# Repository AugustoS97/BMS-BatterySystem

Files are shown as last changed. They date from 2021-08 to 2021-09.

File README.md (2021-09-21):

# BMS-BatterySystem
Repositorio con el diseño de un BMS y una batería como Trabajo de Fin de Máster.
- Autor: Augusto Samuel Hernández Martín
- Tutor: Fernando Luis Rosa González
- Co-Tutor: Iván Rodríguez Méndez
- Titulación: Máster en Ingeniería Industrial
- Universidad de La Laguna, 2021

# Licencia
- El paquete: [GPLv3](LICENSE) © 2021 Augusto Samuel Hernández Martín - Universidad de La Laguna

# Resumen 
El presente Trabajo Fin de Máster consiste en el diseñado y fabricación de un Sistema de Gestión de Batería (BMS), así como una batería modular configurable a diferentes tensiones y capacidades, con el objetivo de poder alimentar sistemas electrónicos aislados como los dispositivos de capturas de índices de significación eco-acústicos. Se ha llevado a cabo el diseño electrónico de los diferentes módulos que forman el sistema de alimentación y gestión así como el cálculo y diseño de la batería a partir de celdas de ion-litio y su estructura mecánica. Para poder alimentar dicho sistema se ha dimensionado una posible instalación generadora, empleando energía fotovoltaica. Finalmente, se ha realizado la fabricación de los distintos elementos, tanto mecánicos como electrónicos, y el desarrollo software de las diferentes herramientas necesarias para la configuración del BMS, la captura y el análisis de los datos generados. Por último, se han propuesto y analizado diferentes aplicaciones, además de la mencionada como objetivo principal del proyecto, para este sistema de BMS y acumulador.

# Abstract

In the present Master’s Degree Final Project, a Battery Management System (BMS) has been designed and manufactured, as well as a modular battery configurable at different voltages and capacities, with the aim of being able to power isolated electronic systems such as devices for capturing eco-acoustic significance indexes. The electronic design of the different modules that make up the power supply and management system has been carried out, as well as the calculation and design of the battery based on lithium-ion cells and its mechanical structure. In order to be able to supply this system, a possible generating installation has been dimensioned, using photovoltaic energy. Finally, the manufacture of the different elements, both mechanical and electronic, and the software development of the different tools necessary for the configuration of the BMS and the capture and analysis of the data generated have been carried out. Finally, different applications have been proposed and analysed, in addition to the one mentioned as the main objective of the project, for this BMS and accumulator system.

# Imágenes del sistema desarrollado
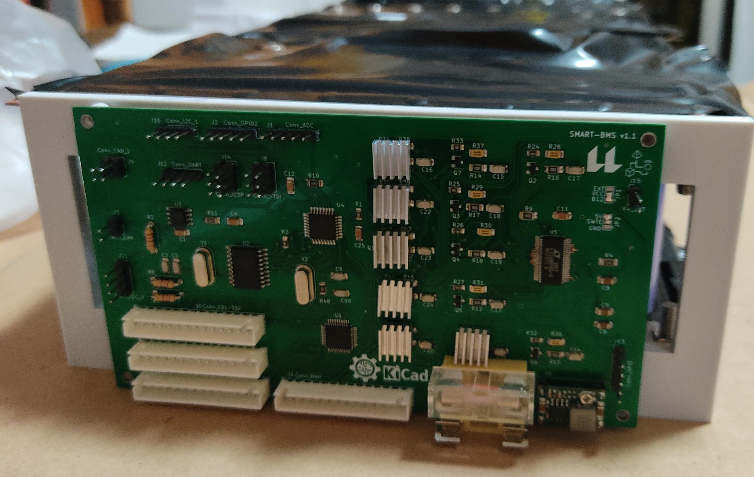
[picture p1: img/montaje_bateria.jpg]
BMS


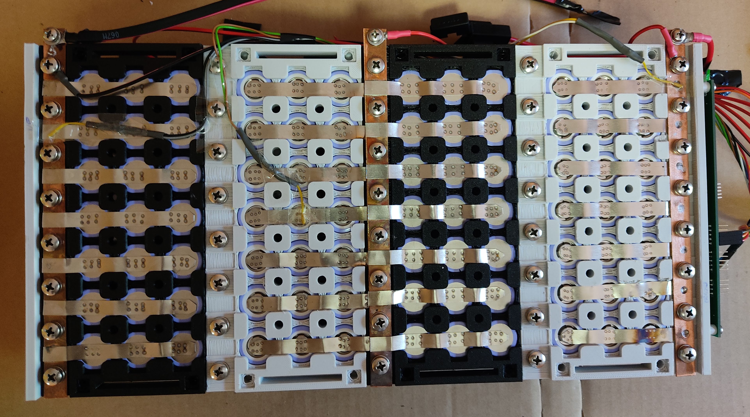
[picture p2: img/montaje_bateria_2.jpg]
Bateria


# Sistema diseñado

El diagrama de bloques del sistema de alimentación y la batería es el siguiente:

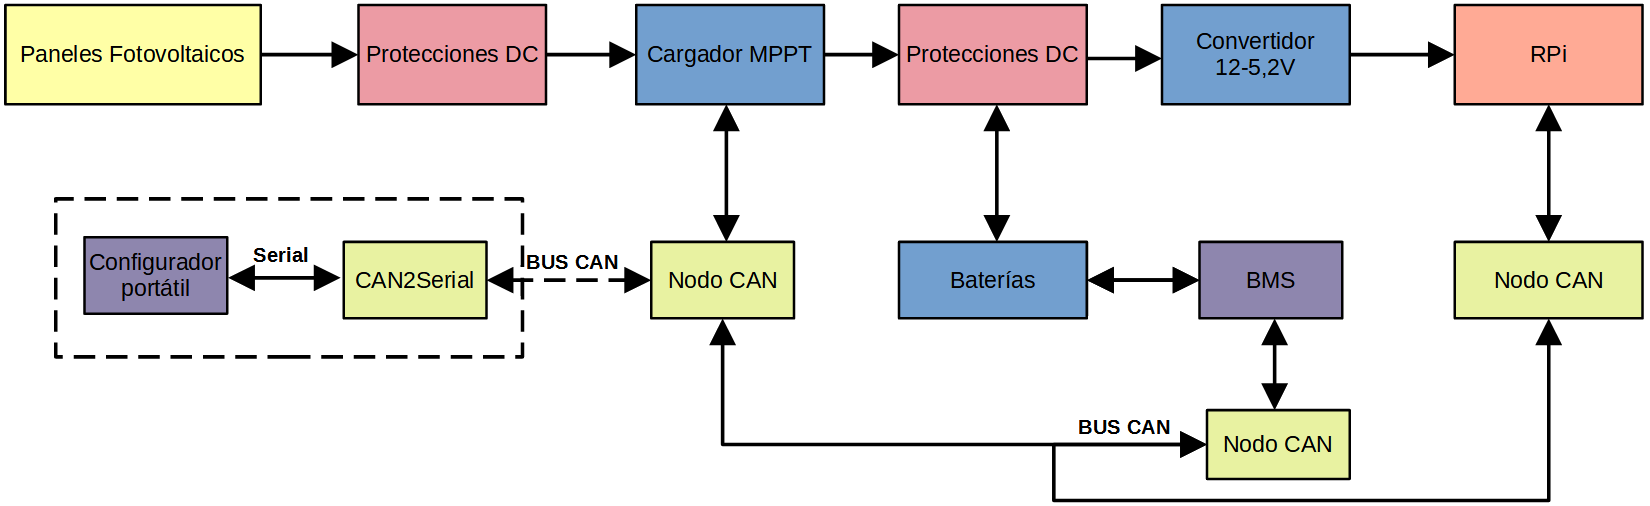
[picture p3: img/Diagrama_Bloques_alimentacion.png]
Diagrama de bloques del Sistema


La batería diseñada es la siguiente:
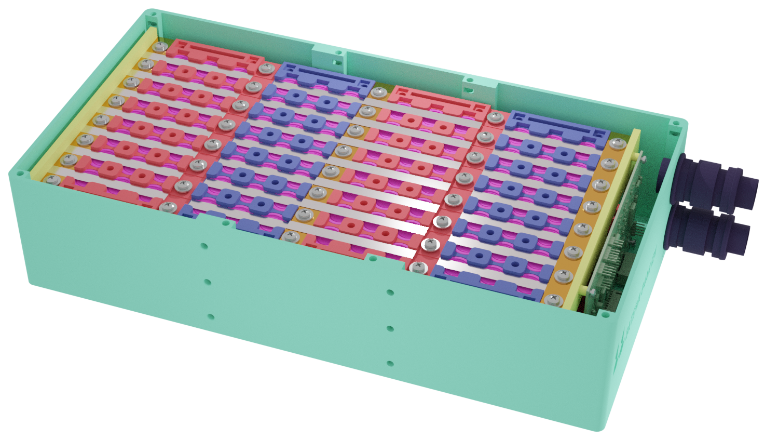
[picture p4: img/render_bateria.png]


Los módulos electrónicos diseñados son los siguientes:

## BMS
Diagrama de bloques del Sistema

## CAN2Serial
Diagrama de bloques del Sistema

## CAN2RS485
Diagrama de bloques del Sistema

# Contenido del repositorio

## Software
- BMS CAN Programmer: Puede encontrarse la herramienta BMS_CAN_Programer_GUI que debe ejecutarse en Linux con Qt 5 instalado. Y el firmware preparado para grabar en un ATMega 328P empleando la herramienta PlatformIo que realiza la conversión de los mensajes CAN del BMS desarrollado a mensajes serial que son leídos por la herramienta BMS_CAN_Programmer_GUI.
- SOC_estimation: Contiene los ficheros .csv de diferentes ensayos realizados a las celdas INR21700 de Samsung y en el directorio /src el script a ejecutar por terminal para obtener las curvas del ensayo. La carpeta /figures contiene las gráficas generadas.
- SmartBMS: Contiene el firmware del microcontrolador ATMega 328P del módulo de BMS. Debe flashearse empleando Platformio.
- bms_data_processing: Herramienta para ejecutar desde terminal e indicar la ruta del fichero .csv de datos del BMS generado así como número de celdas en serie y número de termistores.
-  power-monitor: Herramienta para instalar en una Raspberry Pi 3B+ que monitoriza el consumo de la misma a partir de las lecturas del integrado INA219 vía I2C. Almacena los ficheros capturados en un .json dentro del directorio /usr/share/power/data. Se generta un serivicio del sistema que puede ser gestionado mediante systemd.
-  power-data-processing: Herramienta que genera los gráficos de los datos capturados por power-monitor. Accede directamente a la ruta /home/$USER/power-data/data. Los diferentes ficheros python deben ubicarse en /home/$USER/power-data/src.

## Diseno-Electronico
- SmartBMS: Módulo electrónico de un BMS pra la medición de hasta 12 paquetes de celdas en serie, con comunicación CAN y medición de hasta 32 termistores NTC de 10KOhm. Opera con tensiones de alimentación de hasta 75V.
- CAN2Serial: Módulo electrónico para la interfaz de conversión de CAN a Serial para emplear la herramienta BMS_Programer_GUI y configurar el BMS.
- EPSolar-CAN: Módulo electrónico para la conversión de los mensajes CAN del BMS a mensajes para un cargador solar EPEver (mediante RS485).

## Diseno-Mecanico
- Bateria_horizontal.FCStd: Fichero FreeCAD con el diseño de un sistema de batería modular de 14.4V y 84Ah.
- Carcasa_Can2Serial.FCStd: Fichero FreeCAD con el diseno e la carcasa para la placa de circuito impreso de CAN2Serial
- STL: Contiene los modelos 3D de las diferentes piezas.

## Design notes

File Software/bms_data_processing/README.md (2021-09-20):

# BMS-data-processing
Script de python 3 para ejecutar desde terminal. Permite generar las gráficas de estado de la batería y el BMS a partir de los datos recogidos por el BMS a través de la herramienta BMS-Programmer-GUI. El código fuente se localiza en '/src', las figuras generadas en 'figures' y los datos en 'data'

# Licencia
- El paquete: [GPLv3](LICENSE) © 2021 Augusto Samuel Hernández Martín - Universidad de La Laguna

# Requerimientos Python
Se precisan las siguientes librerías:
~~~
- os
- datetime
- time
- json
- pathlib
- subprocess
- requests
- sys
- numpy
- csv
~~~

# Ejecucion del script

Se debe ejecutar desde terminal como se indica:
~~~
python3 bms-data-processing-d nombre_fichero.csv number_of_cells number_of_temp_sensor
~~~

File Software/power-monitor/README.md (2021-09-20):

# power-data

## Descripción
Software desarrollado para monitorizar el consumo de corriente y la tensión de un
sistema usando el integrado INA-219 (https://pypi.org/project/pi-ina219/) y la conexión I2C a una Raspberry PI.
El servicio del sistema se ejecuta cada 5 minutos y almacena en un fichero .json los
datos capturados del día correspondiente, ordenados en directorios.

# Licencia
- El paquete: [GPLv3](LICENSE) © 2021 Augusto Samuel Hernández Martín - Universidad de La Laguna

## Requerimientos
Requiere el módulo de Python INA219.

    $ sudo apt-get install python3-pip
    $ sudo pip3 install pi-ina219

Para la compilación del paquete .deb requiere:
~~~
  - dh-make
  - debmake
  - debhelper
  - devscripts
  - dpkg-dev
  - make
  - python3
  - build-essential
~~~

## Empaquetado

Para hacer el paquete con el servicio del sistema, se debe ejecutar:

    $ debuild -us -uc

Se debe estar en la carpeta 'power_monitor_d.

Mas información [aquí](https://blog.packagecloud.io/eng/2016/12/15/howto-build-debian-package-containing-simple-shell-scripts/ "Documentación dh-make").

## Localización de la instalación

Una vez instalado el .deb se genera un directorio en /usr/share llamado 'power-data'
que contiene 'src', 'data' y 'logs', donde se aloja el script, los datos y los logs.
Los ficheros del servicio de superusuario se alojan en '/lib/systemd/system'

    $ sudo dpkg -i power-monitor-d_1.0_all.deb

## Desinstalación

Para proceder a desinstalar el paquete, debe ejecutarse:

    $ sudo dpkg -r power-monitor-d

Se eliminan todos los ficheros salvo la ruta '/usr/share/power-data/data' que debe eliminarse a mano (para permitir no perder los datos .json).

## Revisión del estado del timer y el servicio

    $ systemctl status power-monitor-d.service
    $ systemctl status power-monitor-d.timer
    $ systemctl start power-monitor-d.service
    $ systemctl stop power-power_monitor_d.service
    $ systemctl daemon-reload

## Licencia
- El paquete: [GPLv3](LICENSE) © 2021 Augusto Samuel Hernández Martín - Universidad de La Laguna

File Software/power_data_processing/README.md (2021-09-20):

# BMS-data-processing
Script de python 3 para ejecutar desde terminal. Permite generar las gráficas de los datos recogidos por el servicio del sistema 'power-monitor'. La carpeta 'power-data' debe localizar en '/home/$USER/power-data'. El código fuente se localiza en '/src', los logs de procesamiento en '/logs' y los datos en '/data'.

# Licencia
- El paquete: [GPLv3](LICENSE) © 2021 Augusto Samuel Hernández Martín - Universidad de La Laguna

# Estructra de ficheros
El conjunto de ficheros deben de localizarse de la siguiente forma:

~~~
|--- power-data
|--- data
|   |--- Year
|   |   |--- Month
|   |   |   |--- Day
|   |   |   |   |--- power-dataYYMMDDDD.json
|--- src
|   |--- power_data_plot_tools
|   |--- power_data_tools
|   |-- power-data-processing-d
|--- logs
|   |--- _processed_plot.log
|   |--- power-data.log
~~~

# Requerimientos Python
Se precisan las siguientes librerías:
~~~
- matplotlib
- os
- datetime
- time
- json
- pathlib
- subprocess
- requests
- sys
- numpy
- csv
~~~

# Ejecucion del script

Se debe ejecutar desde terminal como se indica:
~~~
python3 power-data-processing-d
~~~

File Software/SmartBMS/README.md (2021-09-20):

# BMS
Firmware del nodo BMS que monitoriza la tensión, la temperatura de las celdas, la corriente
y realiza el balanceo de las celdas, cuando la diferencia entre celdas supera un valor establecido.
Transmite los parámetros medidos por CANBUS y puede ser configurado mediante CANBUS.

# Licencia
- El paquete: [GPLv3](LICENSE) © 2021 Augusto Samuel Hernández Martín - Universidad de La Laguna

# Mensajes CAN
A continuación se indican los mensajes CAN que son intercambiados entre el nodo BMS y el resto de nodos.

### Warning. Mensaje CAN
- Este mensaje es envíado por el BMS cuando hay una sobretemperatura o una tensión demasiado baja o alta. Su ID = 0x00 y está formado por 1 byte. Los bits a 1 indican las alertas que están activas:
  - ID = 0x00 (WARNING_ID)
  - DLC = 1 byte
  - data[0] = x;x;x;x;x;OverTemp;NotCharged;UnderVoltage

### Configurar valor VUV. Mensaje CAN
- Este mensaje configura el valor de tensión mínima de la celda en el BMS.
  - El ID en hexadecimal del mensaje CAN es ID=0x02. (VUV_MSG_ID)
  - DLC = 1 byte
  - Valor (Voltios) = data[0] * 0,02 V
  - Se almacena el valor en la dirección de memoria 0x02 de la EEPROM (VUV_addr)

### Configurar valor VOV. Mensaje CAN
- Este mensaje configura el valor de tensión máxima de la celda. en el BMS
  - El ID en hexadecimal del mensaje CAN es ID=0x03. (VOV_MSG_ID)
  - DLC = 1 byte
  - Valor (Voltios) = data[0] * 0,02 V
  - Se almacena el valor en la dirección de memoria 0x03 de la EEPROM (VOV_addr)

### Configurar valor DCTO. Mensaje CAN
- Este mensaje configura el tiempo que dura la descarga de la celda durante el balanceo (en minutos).
  - El ID en hexadecimal del mensaje CAN es ID=0x04.
  - DLC = 1 byte (DCTO_MSG_ID)
  - Valor = El número indica un tiempo en minutos:
    - "DCTO0\n" = Se desactiva el TimeOut.
    - "DCTO1\n" = Se produce el balanceo de la Celda Cx durante 0.5 minutos
    - "DCTO2\n" = Se produce el balanceo de la Celda Cx durante 1 minuto
    - "DCTO3\n" = Se produce el balanceo de la Celda Cx durante 2 minutos
    - "DCTO4\n" = Se produce el balanceo de la Celda Cx durante 3 minutos
    - "DCTO5\n" = Se produce el balanceo de la Celda Cx durante 4 minutos
    - "DCTO6\n" = Se produce el balanceo de la Celda Cx durante 5 minutos
    - "DCTO7\n" = Se produce el balanceo de la Celda Cx durante 10 minutos
    - "DCTO8\n" = Se produce el balanceo de la Celda Cx durante 15 minutos
    - "DCTO9\n" = Se produce el balanceo de la Celda Cx durante 20 minutos
    - "DCTO10\n" = Se produce el balanceo de la Celda Cx durante 30 minutos
    - "DCTO11\n" = Se produce el balanceo de la Celda Cx durante 40 minutos
    - "DCTO12\n" = Se produce el balanceo de la Celda Cx durante 60 minutos
    - "DCTO13\n" = Se produce el balanceo de la Celda Cx durante 75 minutos
    - "DCTO14\n" = Se produce el balanceo de la Celda Cx durante 90 minutos
    - "DCTO15\n" = Se produce el balanceo de la Celda Cx durante 120 minutos
  - Se almacena el valor en la dirección de memoria 0x04 de la EEPROM (DCTO_addr)

### Configurar valor N_CELL. Mensaje CAN
- Este mensaje configura el número de celdas conectadas en serie en el BMS.
  - El ID en hexadecimal del mensaje CAN es ID=0x05. (NCELL_MSG_ID)
  - DLC = 1 byte
  - Valor = El byte se convierte a un entero de 8 bits e indica el número de celdas entre 1 y 12.  
  - Se almacena el valor en la dirección de memoria 0x05 de la EEPROM (NCELL_addr)

### Configurar valor N_CELL_PARALLEL. Mensaje CAN
- Este mensaje configura el número de celdas conectadas en paralelo en el BMS.
  - El ID en hexadecimal del mensaje CAN es ID=0x0F. (NCELL_PARALLEL_MSG_ID)
  - DLC = 1 byte
  - Valor = El byte se convierte a un entero de 8 bits e indica el número de celdas entre 1 y 99.  
  - Se almacena el valor en la dirección de memoria 0x0A de la EEPROM (NCELL_PARALLEL_addr)

### Configurar valor N_NTC. Mensaje CAN
- Este mensaje configura el número de sensores de temperatura empleados en el BMS.
  - El ID en hexadecimal del mensaje CAN es ID=0x06. (N_NTC_MSG_ID)
  - DLC = 1 byte
  - Valor = El byte se convierte a un entero de 8 bits e indica el número de termistores entre 1 y 32.
  - Se almacena el valor en la dirección de memoria 0x06 de la EEPROM (N_NTC_addr)

### Configurar tiempo que duerme por ciclo el BMS (T_SLEEP). Mensaje CAN
- Este mensaje configura el tiempo en múltiplos de 100 ms que duerme el BMS tras realizar cada ciclo de operaciones.
  - El ID en hexadecimal del mensaje CAN es ID=0x07. (TSLEEP_MSG_ID)
  - DLC = 1 byte
  - Valor = El byte se convierte a un entero de 8 bits y se multiplica por 100 ms para tener el tiempo.
  - Se almacena el valor en la dirección de memoria 0x07 de la EEPROM (TSLEEP_addr)

### Forzar el balanceo de las Celdas 1 a la 8 (C0-C7). Mensaje CAN
- Este mensaje activa el balanceo de las celdas cuyo bit en el byte esté a 1, durante el tiempo almacenado en el DCTO.
  - El ID en hexadecimal es ID=0x08 (BAL1TO8_MSG_ID)
  - DLC = 1 byte
  - Valor = Bits a 1 son las celdas a balancear con *LSB=C0* y *MSB=C7*

### Forzar el balanceo de las Celdas 9 a la 12 (C8-C11). Mensaje CAN
- Este mensaje activa el balanceo de las celdas cuyo bit en el byte esté a 1, durante el tiempo almacenado en el DCTO.
  - El ID en hexadecimal es ID=0x09 (BAL9TO12_MSG_ID)
  - DLC = 1 byte
  - Valor = Bits a 1 son las celdas a balancear con *LSB=C8* y *bit3=C11*
  - ID = 0x09  DLC = 1 data[0] = 0b00001001 -> Balancear celdas 9 (C8) y 12 (C11)

### Configurar el tipo de Balanceo a realizar. Mensaje CAN
- Este mensaje configura si el balanceo de las celdas se realiza durante la carga, la descarga, en ambas o ninguna.
Se envía un mnesaje CAN de 1 byte con los siguientes datos:
  - El ID en hexadecimal es ID = 0x0E (TYPE_BALANCING_MSG_ID)
  - DLC = 1 byte
  - Valor = Bit 0 representa el balanceo en la carga. Bit 1 representa el balanceo en la descarga
    - ID = 0x0E DLC = 1 data[0] = 0b00000001 -> Balancear solo en la carga
    - ID = 0x0E DLC = 1 data[0] = 0b00000010 -> Balancear solo en la descarga
    - ID = 0x0E DLC = 1 data[0] = 0b00000011 -> Balancear en carga y descarga
    - ID = 0x0E DLC = 1 data[0] = 0b00000000 -> No balancear en ningún caso
  - Se almacena el valor en la dirección de memoria 0x09 (BALANCING_TYPE_addr)

### Configurar máxima diferencia entre celdas en mV. Mensaje CAN
- Este mensaje CAN configura la máxima diferencia de tensión en mV admisible entre las diferentes celdas.
  - El ID en hexadecimal es ID=0x0D (MAX_DIFF_CELL_MSG_ID)
  - DLC = 1 byte
  - Valor = data[0] * 1mV
  - Se almacena el valor en la dirección de memoria 0x08 de la EEPROM (MAX_DIFF_CELL_addr)

### Configurar offset del sensor de corriente (en mA). Mensaje CAN
- Este mensaje CAN configura el offset a aplicar en la medida del sensor de corriente. Permite un offset entre -32767 y +32767 mA.
  - El ID en hexadecimal es ID=0x10 (CURRENT_OFFSET_MSG_ID)
  - DLC = 2 byte
  - Valor = ((data[0] << 8) | data[1]) - 32767
  - Se almacena el valor en las direcciones de memoria 0x0B y 0x0C de la EEPROM (CURRENT_OFFSET_addr y CURRENT_OFFSET_addr2)

### Pedir las configuraciones de los BMS. Mensaje CAN
- Este mensaje CAN pide todas las configuraciones almacenadas en la EEPROM del BMS. El ID de este mensaje es ID = 0x0B.
El BMS responde con un mensaje con ID = 0x0C y 8 bytes con los datos que ha obtenido de las direcciones de la EEPROM 0x00 a 0x07.
  - El ID en hexadecimal es ID=0x0B (ASK_CONFIG_MSG_ID)
  - DLC = 1 byte
  - Valor = 255

### Enviar todas las configuraciones almacenadas en el BMS. Mensaje CAN
- Este primer mensaje CAN devuelve los diferentes parámetros de configuración en 8 bytes. Su ID es ID = 0x0C.
  - El ID es ID=0x0C (ANSWER_CONFIG_MSG_ID)
  - DLC = 8 bytes
  - Valores:
    - data[0] = VUV
    - data[1] = VOV
    - data[2] = DCTO
    - data[3] = N_CELL
    - data[4] = N_NTC
    - data[5] = MAX_DIFF_CELL_mV
    - data[6] = CELL_BALANCING_C0_C7
    - data[7] = CELL_BALANCING_C8_C11
- Este segundo mensaje CAN devuelve los parámetros de configuración restantes en 5 bytes. Su ID es ID = 0x11.
  - El ID es ID=0x11 (ANSWER_CONFIG_MSG_2_ID)
  - DLC = 5 bytes
  - Valores:
    - data[0] = NCELL_PARALLEL
    - data[1] = CURRENT_OFFSET (MS Byte)
    - data[2] = CURRENT_OFFSET (LS Byte). En su reconstrucción hay que restarle 32767 a la palabra
    - data[3] = T_SLEEP
    - data[4] = BALANCING_TYPE

### Enviar los valores en Voltios de las celdas 1 a la 4. Mensaje CAN
- Este mensaje envía el voltaje de las celdas C1-C4 cada una de ellas como 2 bytes. El valor obtenido debe multiplicarse por 100 uV para tener el Voltaje de la celda.
  - ID=0x40 (DEC=64) (BAT_MSG1_ID)
  - DLC = 8 bytes
  - Valor C1 = (data[0] | (data[1]<<8)) · 100 uV
  - Valor C2 = (data[2] | (data[3]<<8)) · 100 uV   
  - Valor C3 = (data[4] | (data[5]<<8)) · 100 uV
  - Valor C4 = (data[6] | (data[7]<<8)) · 100 uV

### Enviar los valores en Voltios de las celdas 5 a la 8. Mensaje CAN
- Este mensaje envía el voltaje de las celdas C5-C8 cada una de ellas como 2 bytes. El valor obtenido debe multiplicarse por 100 uV para tener el Voltaje de la celda.
    - ID=0x41 (DEC=65) (BAT_MSG2_ID)
    - DLC = 8 bytes
    - Valor C5 = (data[0] | (data[1]<<8)) · 100 uV
    - Valor C6 = (data[2] | (data[3]<<8)) · 100 uV   
    - Valor C7 = (data[4] | (data[5]<<8)) · 100 uV
    - Valor C8 = (data[6] | (data[7]<<8)) · 100 uV

### Enviar los valores en Voltios de las celdas 9 a la 12. Mensaje CAN
- Este mensaje envía el voltaje de las celdas C9-C12 cada una de ellas como 2 bytes. El valor obtenido debe multiplicarse por 100 uV para tener el Voltaje de la celda.
    - ID=0x42 (DEC=66) (BAT_MSG3_ID)
    - DLC = 8 bytes
    - Valor C9 = (data[0] | (data[1]<<8)) · 100 uV
    - Valor C10 = (data[2] | (data[3]<<8)) · 100 uV   
    - Valor C11 = (data[4] | (data[5]<<8)) · 100 uV
    - Valor C12 = (data[6] | (data[7]<<8)) · 100 uV

### Enviar la Temperatura de las NTC 1 a la 8. Mensaje CAN
- Este mensaje envía cada temperatura en 1 byte de datos.
  - ID = 0x43 (DEC=67) (TEMP_MSG1_ID)
  - DLC = 8 bytes
  - NTC0 a NTC7 = data[0] a data[7]. Debe restarse a cada entero 5 y multiplicar por 0,3.

### Enviar la Temperatura de las NTC 9 a la 16. Mensaje CAN
- Este mensaje envía cada temperatura en 1 byte de datos.
  - ID = 0x44 (DEC=68) (TEMP_MSG2_ID)
  - DLC = 8 bytes
  - NTC8 a NTC15 = data[0] a data[7]. Debe restarse a cada entero 5 y multiplicar por 0,3

### Enviar la Temperatura de las NTC 17 a la 24. Mensaje CAN
- Este mensaje envía cada temperatura en 1 byte de datos.
  - ID = 0x45 (DEC=69) (TEMP_MSG3_ID)
  - DLC = 8 bytes
  - NTC16 a NTC23 = data[0] a data[7]. Debe restarse a cada entero 5 y multiplicar por 0,3

### Enviar la Temperatura de las NTC 24 a la 32. Mensaje CAN
- Este mensaje envía cada temperatura en 1 byte de datos.
  - ID = 0x46 (DEC=70) (TEMP_MSG4_ID)
  - DLC = 8 bytes
  - NTC16 a NTC31 = data[0] a data[7]. Debe restarse a cada entero 5 y multiplicar por 0,3

### Enviar el valor del SOC. Mensaje CAN
- Este mensaje envía el SOC del pack como un valor entre 0-10000 (2 byte) correspondiente a 0-100% multiplicado por 100.
  - ID = 0x47 (DEC=71) (SOC_MSG_ID)
  - DLC = 2 byte
  - Mensaje CAN:
    - data[0] = round(SOC * 100) >> 8
    - data[1] = round(SOC *100) & 0b0000000011111111
  - Valor = (uint16_t(data[1] << 8) | data[0])/100.0

### Enviar el valor del SOH. Mensaje CAN
- Este mensaje envía el SOC del pack como un valor entre 0-10000 (2 byte) correspondiente a 0-100% multiplicado por 100.
  - ID = 0x48 (DEC=72) (SOH_MSG_ID)
  - DLC = 2 byte
  - Mensaje CAN:
    - data[0] = round(SOH * 100) >> 8
    - data[1] = round(SOH *100) & 0b0000000011111111
  - Valor = (uint16_t(data[1] << 8) | data[0])/100.0

### Enviar la corriente que circula por la batería. Mensaje CAN
- Este mensaje envía la corriente medida por el BMS (siendo positiva para la carga de la batería) y negativa para la descarga. Se envía el valor como un entero de 4 bytes
con el valor de corriente en mA. Por ejemplo, la lectura de corriente -23.568 A, se convierto al entero (de 32 bits) -23568 y se envían sus 4 bytes.
  - ID = 0x49 (DEC = 73) (CURRENT_MSG_ID)
  - DLC = 4 bytes
  - Valor = (data[3] << 24 | data[2] << 16 | data[1] << 8 | data[0]) (mA)

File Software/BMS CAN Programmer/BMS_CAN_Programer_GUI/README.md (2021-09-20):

# BMS-CAN-Programmer-GUI
Interfaz gráfica de configuración para el módulo BMS (SmartBMS) a través de la interfaz CAN2Serial.

# Licencia
- El paquete: [GPLv3](LICENSE) © 2021 Augusto Samuel Hernández Martín - Universidad de La Laguna

# Requerimientos de Python 3
Se precisan las siguiente librerías:
~~~
- pyQt 5
- pySerial
- numpy
- time
- os
- threading
- datetime
- csv
~~~

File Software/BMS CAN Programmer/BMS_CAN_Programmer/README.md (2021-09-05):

# BMS_CAN_programer
Firmware del nodo que recibe los datos del CANBUS y comunica con el PC por Serial y configura el BMS por CAN envíando los parámetros transmitidos desde el PC por Serial.

# Licencia
- El paquete: [GPLv3](LICENSE) © 2021 Augusto Samuel Hernández Martín - Universidad de La Laguna

# Mensajes a Enviar por puerto Serial
Para realizar la comunicación con el CAN debe Enviarse un mensaje por serial, configurado a 115200 baudios, formado por:

- 1 caracter ASCII: Es el identificador del mensaje.
- 1 a 3 caracteres numéricos ASCII: Correpsondiente al valor de configuración.
- Salto de línea: Indica el final del mensaje.

### Configurar en el BMS el valor de tensión mínima de celda. VUV

- Se envía un mensaje con ID='A' seguido de un número entre 0 y 255. El valor en voltios corresponde al producto de ese numero por 0,02. Por ejemplo:

  - "A125\n" = 125 * 0,02 = 2,5 V

### Configurar en el BMS el valor de tensión máxima de celda. VOV

  - Se envía un mensaje con ID='B' seguido de un número entre 0 y 255. El valor en voltios corresponde al producto de ese numero por 0,02. Por ejemplo:

    - "B125\n" = 125 * 0,02 = 2,5 V

### Valor de DCTO
- El DCTO es el tiempo que dura activado el balanceo de una celda. Debe Enviarse el ID='C' seguido de uno de los siguientes números:

  - "DCTO0\n" = Se desactiva el TimeOut.
  - "DCTO1\n" = Se produce el balanceo de la Celda Cx durante 0.5 minutos
  - "DCTO2\n" = Se produce el balanceo de la Celda Cx durante 1 minuto
  - "DCTO3\n" = Se produce el balanceo de la Celda Cx durante 2 minutos
  - "DCTO4\n" = Se produce el balanceo de la Celda Cx durante 3 minutos
  - "DCTO5\n" = Se produce el balanceo de la Celda Cx durante 4 minutos
  - "DCTO6\n" = Se produce el balanceo de la Celda Cx durante 5 minutos
  - "DCTO7\n" = Se produce el balanceo de la Celda Cx durante 10 minutos
  - "DCTO8\n" = Se produce el balanceo de la Celda Cx durante 15 minutos
  - "DCTO9\n" = Se produce el balanceo de la Celda Cx durante 20 minutos
  - "DCTO10\n" = Se produce el balanceo de la Celda Cx durante 30 minutos
  - "DCTO11\n" = Se produce el balanceo de la Celda Cx durante 40 minutos
  - "DCTO12\n" = Se produce el balanceo de la Celda Cx durante 60 minutos
  - "DCTO13\n" = Se produce el balanceo de la Celda Cx durante 75 minutos
  - "DCTO14\n" = Se produce el balanceo de la Celda Cx durante 90 minutos
  - "DCTO15\n" = Se produce el balanceo de la Celda Cx durante 120 minutos

### Número de celdas conectadas
- Configura el número de celdas en serie conectadas al BMS, comenzando por la celda C0. Se debe Enviar el ID='D' seguido de un numero entre 1 y 12 para indicar el número de celdas:
  - "D12\n" = Configurar 12 celdas en serie

### Número de Termistores (NTC) conectados
- Configura el número de NTC conectadas al BMS, comenzando por la NTC0. Se debe Enviar el ID='E' seguido de un numero entre 1 y 32 para indicar el número de sensores:
  - "E12\n" = Configurar 12 sensores NTC

### Máxima diferencia de voltaje entre celdas
- Configura la diferencia de tensión máxima admisible entre celdas. Este parámetro es utilizado por el algoritmo de balanceo para activar el balanceo de las celdas cuando se supera este umbral. Debe Enviarse el ID='I' seguido de un número entre 0 y 255 que indica los mV máximos de diferencia:
  - "I220\n" = Máxima diferencia admisible entre celdas de 220 mV

### Forzar el balanceo de las celdas 1 a la 8 (C0-C7)
- Activa el balanceo de las celdas cuyas posiciones en el byte estén a 1 (siendo el *LSB= C0* y *MSB=C7*), durante el tiempo indicado mediante el mensaje de *configurar DCTO*. Debe Enviarse el ID='G' seguido de 1 byte indicando las celdas a balancear:
  - "G57\n" = Balancear las celdas 1,4,5 y 6 (0b00111001)

### Forzar el balanceo de las celdas 9 a la 12 (C8-C11)
- Activa el balanceo de las celdas cuyas posiciones en el byte estén a 1 (siendo el *LSB= C8* y *bit4=C11*), durante el tiempo indicado mediante el mensaje de *configurar DCTO*. Debe Enviarse el ID='H' seguido de 1 byte indicando las celdas a balancear:
  - "H9\n" = Balancear las celdas 9 y 12 (C8 y 11) )(0b00001001).

### Activar o desactivar el balanceo automático
- Activa el balanceo de las celdas de forma automática durante la carga de la batería, la descarga o ambas, durante el tiempo indicado mediante el mensaje de *configurar DCTO*. Debe Enviarse el ID='J' seguido de 2 bits que indican el tipo de balanceo:
  - "J0\n" = Balanceo desactivado (0b00)
  - "J1\n" = Balanceo exclusivamente durante la carga (0b01)
  - "J2\n" = Balanceo exclusivamente durante la descarga (0b10)
  - "J3\n  = Balanceo durante la carga y la descarga(0b11)

### Numero de celdas conectadas en paralelo
- Configura el número de celdas conectadas en paralelo en el BMS. Debe envisarse el ID='K' seguido del valor (número de celdas):
  - "K10\n" = 10 celdas conectadas en paralelo

### Offset del sensor de Corriente
- Configura el offset a aplicar en la medida de corriente. Debe enviarse el ID='L' seguido del valor (positivo o negativo) entre -220 y 220 mA:
  - "L-110\n" = Offset de -110 mA en la medida de corriente

### Tiempo que duerme por ciclo
- Configura el tiempo de reposo en cada ciclo del BMS. Debe enviarse el ID='F' seguido de un valor entre 0 y 255 que es el tiempo en ms que duerme el BMS.
  - "F10\n" = Tiempo de reposo de 10 ms

### Pedir los valores de configuracion de la EEPROM del BMS.
- Pide todos los parámetros de configuración que presenta almacenados el BMS en su EEPROM. Debe Enviarse el ID='Z' seguido de un 1:
  - "Z1\n" = Pedir todos los parámetros de configuración.
- Se espera recibir dos mensaje, uno de 8 bytes y otro de 5 por CAN, con 1 byte por valor de configuración en el siguiente orden (desde el LSB al MSB): VUV, VOV, DCTO, NCELL, NNTC, DIF_CELL_V, CELL_BALANCING_C0-C7, CELL_BALANCING_C8-C11 para el primer mensaje. El segundo mensaje presenta (desde LSB a MSB): NCELL_PARALLEL, CURRENT_OFFSET, CURRENT_OFFSET_SIGN, T_SLEEP, TYPE_BALANCING

# Mensajes a recibir por puerto Serial
Por Puerto Serie se reciben en el PC los valores configurados con los comandos anteriores, una vez son pedidos al BMS, así como los parámetros medidos por el mismo. Los indicadores de los mensajes recibidos se corresponden con los indicadores de los mensajes envíados por serial.

### Obtener del BMS el valor de tensión mínima de celda. VUV

- Se recibe un mensaje con ID='A' seguido de un número entre 0 y 255. El valor en voltios corresponde al producto de ese numero por 0,02. Por ejemplo:

  - "A125\n" = 125 * 0,02 = 2,5 V

### Obtener del BMS el valor de tensión máxima de celda. VOV

  - Se recibe un mensaje con ID='B' seguido de un número entre 0 y 255. El valor en voltios corresponde al producto de ese numero por 0,02. Por ejemplo:

    - "B125\n" = 125 * 0,02 = 2,5 V

### Obtener el valor de DCTO
- El DCTO es el tiempo que dura activado el balanceo de una celda. Cuando se ha solicitado su valor, se recibe el ID='C' seguido de uno de los siguientes números:

  - "DCTO0\n" = Se desactiva el TimeOut.
  - "DCTO1\n" = Se produce el balanceo de la Celda Cx durante 0.5 minutos
  - "DCTO2\n" = Se produce el balanceo de la Celda Cx durante 1 minuto
  - "DCTO3\n" = Se produce el balanceo de la Celda Cx durante 2 minutos
  - "DCTO4\n" = Se produce el balanceo de la Celda Cx durante 3 minutos
  - "DCTO5\n" = Se produce el balanceo de la Celda Cx durante 4 minutos
  - "DCTO6\n" = Se produce el balanceo de la Celda Cx durante 5 minutos
  - "DCTO7\n" = Se produce el balanceo de la Celda Cx durante 10 minutos
  - "DCTO8\n" = Se produce el balanceo de la Celda Cx durante 15 minutos
  - "DCTO9\n" = Se produce el balanceo de la Celda Cx durante 20 minutos
  - "DCTO10\n" = Se produce el balanceo de la Celda Cx durante 30 minutos
  - "DCTO11\n" = Se produce el balanceo de la Celda Cx durante 40 minutos
  - "DCTO12\n" = Se produce el balanceo de la Celda Cx durante 60 minutos
  - "DCTO13\n" = Se produce el balanceo de la Celda Cx durante 75 minutos
  - "DCTO14\n" = Se produce el balanceo de la Celda Cx durante 90 minutos
  - "DCTO15\n" = Se produce el balanceo de la Celda Cx durante 120 minutos

### Obtener número de celdas conectadas
- Se obtiene el número de celdas conectadas comenzando por la celda C0. Se recibe el ID='D' seguido de un numero entre 1 y 12 para indicar el número de celdas:
  - "D12\n" = Configurar 12 celdas en serie

### Obtener número de Termistores (NTC) conectados
- Se obtiene el número de NTC conectadas al BMS, comenzando por la NTC0. Se recibe el ID='E' seguido de un numero entre 1 y 32 para indicar el número de sensores:
  - "E12\n" = Configurar 12 sensores NTC

### Tiempo que duerme por ciclo
- Se obtiene el tiempo de reposo en cada ciclo del BMS. Se recibe el ID='F' seguido de un valor entre 0 y 255 que es el tiempo en ms que duerme el BMS.
  - "F10\n" = Tiempo de reposo de 10 ms

### Obtener celdas entre la celda 1 y la celda 8 (C0-C7) balanceandose
- Se obtiene las celdas que se están balanceando en un numero decimal cuyas posiciones en el byte estén a 1 para las celdas que se están balanceando (siendo el *LSB= C0* y *MSB=C7*). Se recibe el ID='G' seguido de 1 byte indicando las celdas que se están balanceando:
  - "G57\n" = Las celdas 1,4,5 y 6 (0b00111001) se están balanceando.

### Obtener celdas entre la celda 9 y la celda 12 (C8-C11) balanceandose
- Se obtiene las celdas que se están balanceando como aquellas cuyas posiciones en el byte estén a 1 (siendo el *LSB= C8* y *bit4=C11*). Se recibe el ID='H' seguido de 1 byte decimal indicando las celdas que se están balanceando:
  - "H9\n" =Las celdas 9 y 12 (0b00001001) (C8 y 11) están balanceandose.

### Obtener la máxima diferencia de voltaje entre celdas
- Se obtiene la diferencia de tensión máxima admisible entre celdas. Se recibe el ID='I' seguido de un número entre 0 y 255 que indica los mV máximos de diferencia almacenados en el BMS:
  - "I220\n" = Máxima diferencia admisible entre celdas de 220 mV

### Activar o desactivar el balanceo automático
- Se obtiene el tipo de balanceo que se realiza a las celdas. Se recibe el ID='J' seguido de 2 bits que indican el tipo de balanceo:
  - "J0\n" = Balanceo desactivado
  - "J1\n" = Balanceo exclusivamente durante la carga
  - "J2\n" = Balanceo exclusivamente durante la descarga
  - "J3\n  = Balanceo durante la carga y la descarga

### Obtener numero de celdas conectadas en paralelo
- Se obtiene el número de celdas conectadas en paralelo en el BMS. Se recibe el ID='K' seguido del valor (número de celdas):
  - "K10\n" = 10 celdas conectadas en paralelo

### Obtener Offset del sensor de Corriente
- Se obtiene el offset a aplicar en la medida de corriente. Se recibe el ID='L' seguido del valor (positivo o negativo) entre -220 y 220 mA:
  - "L-110\n" = Offset de -110 mA en la medida de corriente

### Voltaje de las celdas 1 a la 4 (C0-C3)
- Se obtiene la tensión de las celdas C0-C3 mediante mensajes seriales con ID='M' seguido del número de la celda y un valor entre 0 y 65536 que se debe multiplicar por 100 uV para obtener la tensión de la celda.
  - "M163000\n" = El voltaje de la celda 1 es 63000 * 100 * 10^(-6) = 6,3 V

### Voltaje de las celdas 5 a la 8 (C4-C7)
- Se obtiene la tensión de las celdas C4-C7 mediante mensajes seriales con ID='N' seguido del número de la celda y un valor entre 0 y 65536 que se debe multiplicar por 100 uV para obtener la tensión de la celda.
  - "N163000\n" = El voltaje de la celda 1 es 63000 * 100 * 10^(-6) = 6,3 V

### Voltaje de las celdas 9 a la 12 (C8-C11)
- Se obtiene la tensión de las celdas C8-C11 mediante mensajes seriales con ID='O' seguido del número de la celda y un valor entre 0 y 65536 que se debe multiplicar por 100 uV para obtener la tensión de la celda.
  - "O163000\n" = El voltaje de la celda 1 es 63000 * 100 * 10^(-6) = 6,3 V

### Temperatura medida por la NTCx
- Se obtiene la temperatura de la NTCx como un byte que debe convertirse a un entero, restarle 5 y multiplicarse por 0.3 para obtener la Temperatura en ºC. Se recibe el ID='P' seguido de un número entre 01 y 32 (2 bytes de caracteres ASCII) y posteriormente un valor entre 0 y 255 correspondiente a la temperatura:
  - "P08225\n" = Temperatura de la celda 8 es de (225 - 5)*0.3 = 66 ºC

### Valor de la corriente medida en la batería
- Se obtiene el valor de la corriente a partir de la reconstrucción del entero partiendo de 4 bytes de datos. Se recibe el valor de la corriente en mA y separado en 4 bytes, que se reconstruyen como se muestra a continuación:
  - current = ((can_msg_in.data[0]) | (can_msg_in.data[1] << 8) | (can_msg_in.data[2] << 16) | (can_msg_in.data[3] << 24))
- El ID que se envía por puerto serie es ID='Q' seguido del valor de corriente (mA) en decimal.
  - "Q-16452\n" = Corriente de -16.542 Amperios (descarga)

### Valor de SOC del Pack
- Se obtiene el valor del estado de carga como dos byte que representa el porcentaje entre 0 y 100 multiplicado por 100. Se recibe por serial en el PC el ID='T' seguido del porcentaje multiplicado por 100. Ese valor debe dividirse entre 100:
 - "T9980\n" = el SOC es de 99,80 %

### Valor de SOH del Pack
- Se obtiene el valor del estado de salud como dos byte que representa el porcentaje entre 0 y 100. Se recibe por serial en el PC el ID='U' seguido de un valor entre 0 y 100 multiplicado por 100. Ese valor debe dividirse entre 100:
  - "U9980\n" = el SOH es de 99.80 %

# Mensajes CAN de Configuracion
A continuación se indican los mensajes CAN que son intercambiados entre el nodo de configuracion/monitoreo y el nodo BMS.

### Warning. Mensaje CAN
- Este mensaje se envía cuando hay una sobretemperatura o una tensión demasiado baja o alta. Su ID = 0x00 y está formado por 1 byte. Los bits a 1 indican las alertas que están activas:
  - ID = 0x00 (WARNING_ID)
  - DLC = 1 byte
  - data[0] = x;x;x;x;x;OverTemp;NotCharged;UnderVoltage

### Configurar valor VUV. Mensaje CAN
- Este mensaje configura el valor de tensión mínima de la celda.
  - El ID en hexadecimal del mensaje CAN es ID=0x02. (VUV_MSG_ID)
  - DLC = 1 byte
  - Valor (Voltios) = data[0] * 0,02 V

### Configurar valor VOV. Mensaje CAN
- Este mensaje configura el valor de tensión máxima de la celda.
  - El ID en hexadecimal del mensaje CAN es ID=0x03. (VOV_MSG_ID)
  - DLC = 1 byte
  - Valor (Voltios) = data[0] * 0,02 V

### Configurar valor DCTO. Mensaje CAN
- Este mensaje configura el tiempo que dura la descarga de la celda durante el balanceo.
  - El ID en hexadecimal del mensaje CAN es ID=0x04.
  - DLC = 1 byte (DCTO_MSG_ID)
  - Valor = El número indica un tiempo en minutos:
    - "DCTO0\n" = Se desactiva el TimeOut.
    - "DCTO1\n" = Se produce el balanceo de la Celda Cx durante 0.5 minutos
    - "DCTO2\n" = Se produce el balanceo de la Celda Cx durante 1 minuto
    - "DCTO3\n" = Se produce el balanceo de la Celda Cx durante 2 minutos
    - "DCTO4\n" = Se produce el balanceo de la Celda Cx durante 3 minutos
    - "DCTO5\n" = Se produce el balanceo de la Celda Cx durante 4 minutos
    - "DCTO6\n" = Se produce el balanceo de la Celda Cx durante 5 minutos
    - "DCTO7\n" = Se produce el balanceo de la Celda Cx durante 10 minutos
    - "DCTO8\n" = Se produce el balanceo de la Celda Cx durante 15 minutos
    - "DCTO9\n" = Se produce el balanceo de la Celda Cx durante 20 minutos
    - "DCTO10\n" = Se produce el balanceo de la Celda Cx durante 30 minutos
    - "DCTO11\n" = Se produce el balanceo de la Celda Cx durante 40 minutos
    - "DCTO12\n" = Se produce el balanceo de la Celda Cx durante 60 minutos
    - "DCTO13\n" = Se produce el balanceo de la Celda Cx durante 75 minutos
    - "DCTO14\n" = Se produce el balanceo de la Celda Cx durante 90 minutos
    - "DCTO15\n" = Se produce el balanceo de la Celda Cx durante 120 minutos

### Configurar valor N_CELL. Mensaje CAN
- Este mensaje configura el número de celdas conectadas en serie.
  - El ID en hexadecimal del mensaje CAN es ID=0x05. (NCELL_MSG_ID)
  - DLC = 1 byte
  - Valor = El byte se convierte a un entero de 8 bits e indica el número de celdas entre 1 y 12.  

### Configurar valor N_NTC. Mensaje CAN
- Este mensaje configura el número de sensores de temperatura empleados.
  - El ID en hexadecimal del mensaje CAN es ID=0x06. (N_NTC_MSG_ID)
  - DLC = 1 byte
  - Valor = El byte se convierte a un entero de 8 bits e indica el número de termistores entre 1 y 32.  

### Configurar valor N_CELL_PARALLEL. Mensaje CAN
- Este mensaje configura el número de celdas conectadas en paralelo en el BMS.
  - El ID en hexadecimal del mensaje CAN es ID=0x0F. (NCELL_PARALLEL_MSG_ID)
  - DLC = 1 byte
  - Valor = El byte se convierte a un entero de 8 bits e indica el número de celdas entre 1 y 99.  
  - Se almacena el valor en la dirección de memoria 0x0A de la EEPROM (NCELL_PARALLEL_addr)

### Configurar tiempo que duerme por ciclo el BMS (T_SLEEP). Mensaje CAN
- Este mensaje configura el tiempo en múltiplos de 15 ms que duerme el BMS tras realizar cada ciclo de operaciones.
  - El ID en hexadecimal del mensaje CAN es ID=0x07. (TSLEEP_MSG_ID)
  - DLC = 1 byte
  - Valor = El byte se convierte a un entero de 8 bits y se multiplica por 100 ms para tener el tiempo.

### Forzar el balanceo de las Celdas 1 a la 8 (C0-C7). Mensaje CAN
- Este mensaje activa el balanceo de las celdas cuyo bit en el byte esté a 1, durante el tiempo almacenado en el DCTO.
  - El ID en hexadecimal es ID=0x08 (BAL1TO8_MSG_ID)
  - DLC = 1 byte
  - Valor = Bits a 1 son las celdas a balancear con *LSB=C0* y *MSB=C7*

### Forzar el balanceo de las Celdas 9 a la 12 (C8-C11). Mensaje CAN
- Este mensaje activa el balanceo de las celdas cuyo bit en el byte esté a 1, durante el tiempo almacenado en el DCTO.
  - El ID en hexadecimal es ID=0x09 (BAL9TO12_MSG_ID)
  - DLC = 1 byte
  - Valor = Bits a 1 son las celdas a balancear con *LSB=C8* y *bit3=C11*
  - ID = 0x09  DLC = 1 data[0] = 0b00001001 -> Balancear celdas 9 (C8) y 12 (C11)

### Configurar el tipo de Balanceo a realizar. Mensaje CAN
- Este mensaje configura si el balanceo de las celdas se realiza durante la carga, la descarga, en ambas o ninguna.
Se envía un mnesaje CAN de 1 byte con los siguientes datos:
  - El ID en hexadecimal es ID = 0x0E (TYPE_BALANCING_MSG_ID)
  - DLC = 1 byte
  - Valor = Bit 0 representa el balanceo en la carga. Bit 1 representa el balanceo en la descarga
    - ID = 0x0E DLC = 1 data[0] = 0b00000001 -> Balancear solo en la carga
    - ID = 0x0E DLC = 1 data[0] = 0b00000010 -> Balancear solo en la descarga
    - ID = 0x0E DLC = 1 data[0] = 0b00000011 -> Balancear en carga y descarga
    - ID = 0x0E DLC = 1 data[0] = 0b00000000 -> No balancear en ningún caso

### Configurar máxima diferencia entre celdas en mV. Mensaje CAN
- Este mensaje CAN configura la máxima diferencia de tensión en mV admisible entre las diferentes celdas.
  - El ID en hexadecimal es ID=0x0D (MAX_DIFF_CELL_MSG_ID)
  - DLC = 1 byte
  - Valor = data[0] * 1mV

### Configurar offset del sensor de corriente (en mA). Mensaje CAN
- Este mensaje CAN configura el offset a aplicar en la medida del sensor de corriente. Permite un offset entre -32767 y +32767 mA.
  - El ID en hexadecimal es ID=0x10 (CURRENT_OFFSET_MSG_ID)
  - DLC = 2 byte
  - Valor = ((data[0] << 8) | data[1]) - 32767
  - Se almacena el valor en las direcciones de memoria 0x0B y 0x0C de la EEPROM (CURRENT_OFFSET_addr y CURRENT_OFFSET_addr2)

### Pedir las configuraciones de los BMS. Mensaje CAN
- Este mensaje CAN pide todas las configuraciones almacenadas en la EEPROM del BMS. El ID de este mensaje es ID = 0x0B. El BMS responde con un mensaje con ID = 0x0C y 8 bytes con los datos.
  - El ID en hexadecimal es ID=0x0B (ASK_CONFIG_MSG_ID)
  - DLC = 1 byte
  - Valor = 255

### Enviar todas las configuraciones almacenadas en el BMS. Mensaje CAN
- Este primer mensaje CAN devuelve los diferentes parámetros de configuración en 8 bytes. Su ID es ID = 0x0C.
  - El ID es ID=0x0C (ANSWER_CONFIG_MSG_ID)
  - DLC = 8 bytes
  - Valores:
    - data[0] = VUV
    - data[1] = VOV
    - data[2] = DCTO
    - data[3] = N_CELL
    - data[4] = N_NTC
    - data[5] = MAX_DIFF_CELL_mV
    - data[6] = CELL_BALANCING_C0_C7
    - data[7] = CELL_BALANCING_C8_C11
- Este segundo mensaje CAN devuelve los parámetros de configuración restantes en 4 bytes. Su ID es ID = 0x11.
  - El ID es ID=0x11 (ANSWER_CONFIG_MSG_2_ID)
  - DLC = 4 bytes
  - Valores:
    - data[0] = NCELL_PARALLEL
    - data[1] = CURRENT_OFFSET (MS Byte)
    - data[2] = CURRENT_OFFSET (LS Byte). En su reconstrucción hay que restarle 32767 a la palabra
    - data[3] = T_SLEEP
    - data[4] = BALANCING_TYPE

### Enviar los valores en Voltios de las celdas 1 a la 4. Mensaje CAN
- Este mensaje envía el voltaje de las celdas C0-C3 cada una de ellas como 2 bytes. El valor obtenido debe multiplicarse por 100 uV para tener el Voltaje de la celda.
  - ID=0x40 (DEC=64) (BAT_MSG1_ID)
  - DLC = 8 bytes
  - Valor C0 = (data[0] | (data[1]<<8)) · 100 uV
  - Valor C1 = (data[2] | (data[3]<<8)) · 100 uV   
  - Valor C0 = (data[4] | (data[5]<<8)) · 100 uV
  - Valor C0 = (data[6] | (data[7]<<8)) · 100 uV

### Enviar los valores en Voltios de las celdas 5 a la 8. Mensaje CAN
- Este mensaje envía el voltaje de las celdas C4-C7 cada una de ellas como 2 bytes. El valor obtenido debe multiplicarse por 100 uV para tener el Voltaje de la celda.
    - ID=0x41 (DEC=65) (BAT_MSG2_ID)
    - DLC = 8 bytes
    - Valor C4 = (data[0] | (data[1]<<8)) · 100 uV
    - Valor C5 = (data[2] | (data[3]<<8)) · 100 uV   
    - Valor C6 = (data[4] | (data[5]<<8)) · 100 uV
    - Valor C7 = (data[6] | (data[7]<<8)) · 100 uV

### Enviar los valores en Voltios de las celdas 9 a la 12. Mensaje CAN
- Este mensaje envía el voltaje de las celdas C8-C11 cada una de ellas como 2 bytes. El valor obtenido debe multiplicarse por 100 uV para tener el Voltaje de la celda.
    - ID=0x42 (DEC=66) (BAT_MSG3_ID)
    - DLC = 8 bytes
    - Valor C8 = (data[0] | (data[1]<<8)) · 100 uV
    - Valor C9 = (data[2] | (data[3]<<8)) · 100 uV   
    - Valor C10 = (data[4] | (data[5]<<8)) · 100 uV
    - Valor C11 = (data[6] | (data[7]<<8)) · 100 uV

### Enviar la Temperatura de las NTC 1 a la 8. Mensaje CAN
- Este mensaje envía cada temperatura en 1 byte de datos.
  - ID = 0x43 (DEC=67) (TEMP_MSG1_ID)
  - DLC = 8 bytes
  - NTC0 a NTC7 = data[0] a data[7]. Debe restarse a cada entero 5 y multiplicar por 0,3.

### Enviar la Temperatura de las NTC 9 a la 16. Mensaje CAN
- Este mensaje envía cada temperatura en 1 byte de datos.
  - ID = 0x44 (DEC=68) (TEMP_MSG2_ID)
  - DLC = 8 bytes
  - NTC8 a NTC15 = data[0] a data[7]. Debe restarse a cada entero 5 y multiplicar por 0,3

### Enviar la Temperatura de las NTC 17 a la 24. Mensaje CAN
- Este mensaje envía cada temperatura en 1 byte de datos.
  - ID = 0x45 (DEC=69) (TEMP_MSG3_ID)
  - DLC = 8 bytes
  - NTC16 a NTC23 = data[0] a data[7]. Debe restarse a cada entero 5 y multiplicar por 0,3

### Enviar la Temperatura de las NTC 24 a la 32. Mensaje CAN
- Este mensaje envía cada temperatura en 1 byte de datos.
  - ID = 0x46 (DEC=70) (TEMP_MSG4_ID)
  - DLC = 8 bytes
  - NTC16 a NTC31 = data[0] a data[7]. Debe restarse a cada entero 5 y multiplicar por 0,3

### Enviar el valor del SOC. Mensaje CAN
- Este mensaje envía el SOC del pack como un valor entre 0-10000 (2 byte) correspondiente a 0-100% multiplicado por 100.
  - ID = 0x47 (DEC=71) (SOC_MSG_ID)
  - DLC = 2 byte
  - Mensaje CAN:
    - data[0] = round(SOC * 100) >> 8
    - data[1] = round(SOC *100) & 0b0000000011111111
  - Valor = (uint16_t(data[1] << 8) | data[0])/100.0

### Enviar el valor del SOH. Mensaje CAN
- Este mensaje envía el SOC del pack como un valor entre 0-10000 (2 byte) correspondiente a 0-100% multiplicado por 100.
  - ID = 0x48 (DEC=72) (SOH_MSG_ID)
  - DLC = 2 byte
  - Mensaje CAN:
    - data[0] = round(SOH * 100) >> 8
    - data[1] = round(SOH *100) & 0b0000000011111111
  - Valor = (uint16_t(data[1] << 8) | data[0])/100.0

### Enviar la corriente que circula por la batería. Mensaje CAN
- Este mensaje envía la corriente medida por el BMS (siendo positiva para la carga de la batería) y negativa para la descarga. Se envía el valor como un entero de 4 bytes
  con el valor de corriente en mA. Por ejemplo, la lectura de corriente -23.568 A, se convierto al entero (de 32 bits) -23568 y se envían sus 4 bytes.
  - ID = 0x49 (DEC = 73) (CURRENT_MSG_ID)
  - DLC = 4 bytes
  - Valor = (data[3] << 24 | data[2] << 16 | data[1] << 8 | data[0]) (mA)

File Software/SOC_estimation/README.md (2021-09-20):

# BMS-data-processing

Script de python 3 para ejecutar desde terminal. Permite generar las gráficas de estimación del SOC de la celda a partir de un .csv generado por la carga electrónica Rigol DL3010 (https://www.venotek.no/display.aspx?menuid=40017&prodid=5545). Se indica un grado para la estimación polinómica y el valor de resistencia interna de la celda y se obtiene por salida de consola la expresión polinómica que se ajusta a la curva para ese grado. El código fuente se localiza en '/src', las figuras generadas en 'figures' y los datos en 'data'.

# Licencia
- El paquete: [GPLv3](LICENSE) © 2021 Augusto Samuel Hernández Martín - Universidad de La Laguna

# Requerimientos Python
Se precisan las siguientes librerías:
~~~
- os
- datetime
- time
- json
- pathlib
- subprocess
- requests
- sys
- numpy
- csv
~~~

# Ejecucion del script

Se debe ejecutar desde terminal como se indica:
~~~
python3 estimate_SOC.py nombre_fichero.csv grado_regresion_polinomica internal_resistor
~~~

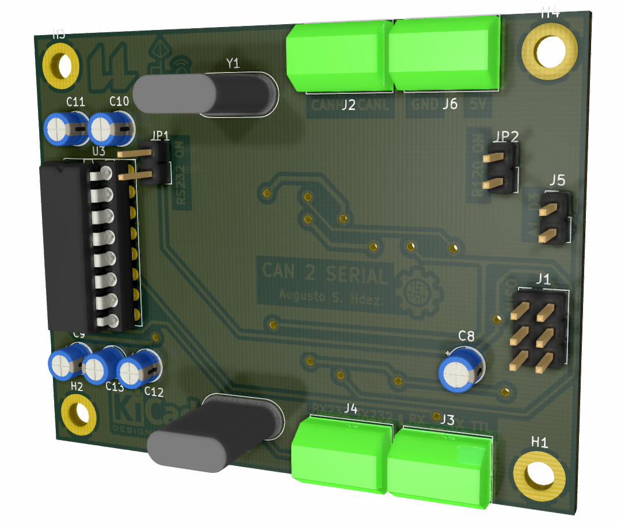
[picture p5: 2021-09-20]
Diseno-Electronico/CAN2Serial/RENDER/render_3.png

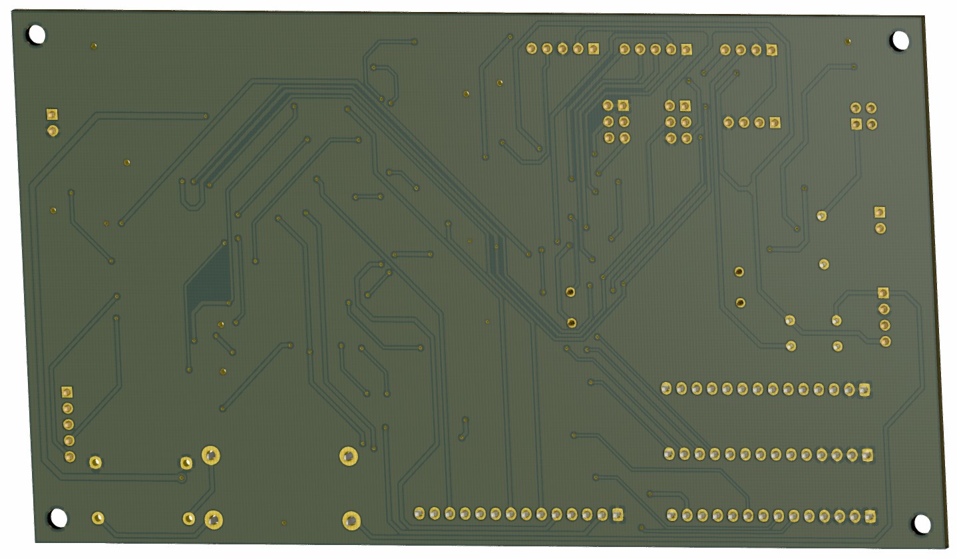
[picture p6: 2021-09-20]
Diseno-Electronico/SmartBMS/RENDER/render_1.jpg

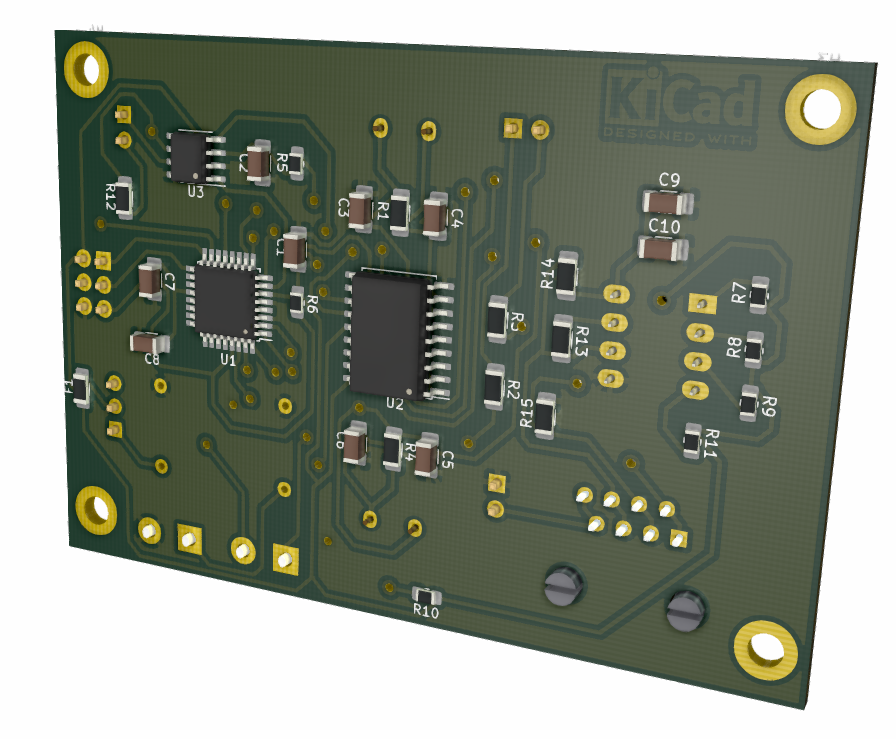
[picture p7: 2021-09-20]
Diseno-Electronico/EPSolar-CAN/RENDER/render_1.png

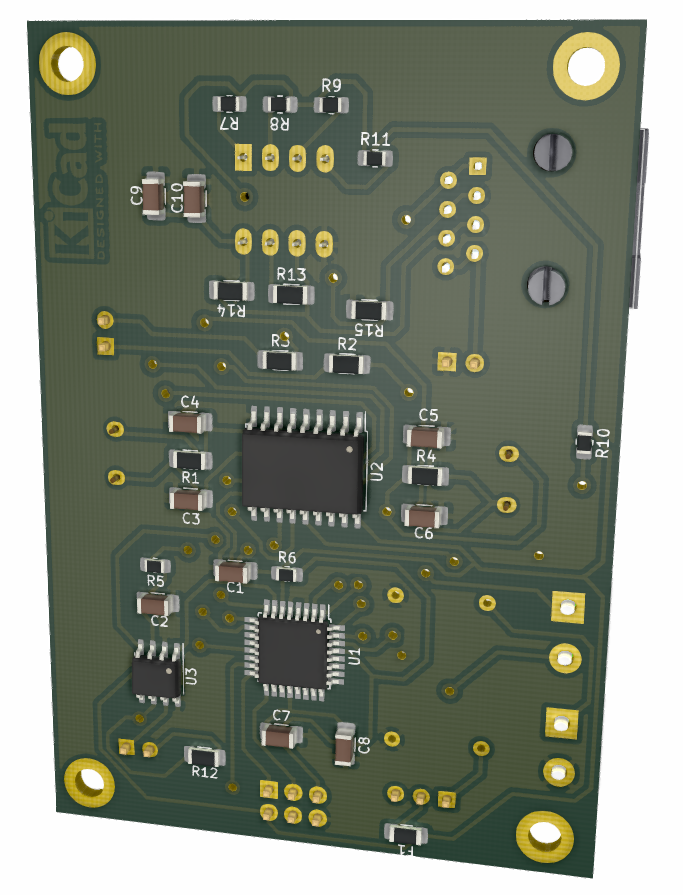
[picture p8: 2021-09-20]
Diseno-Electronico/EPSolar-CAN/RENDER/render_3.png

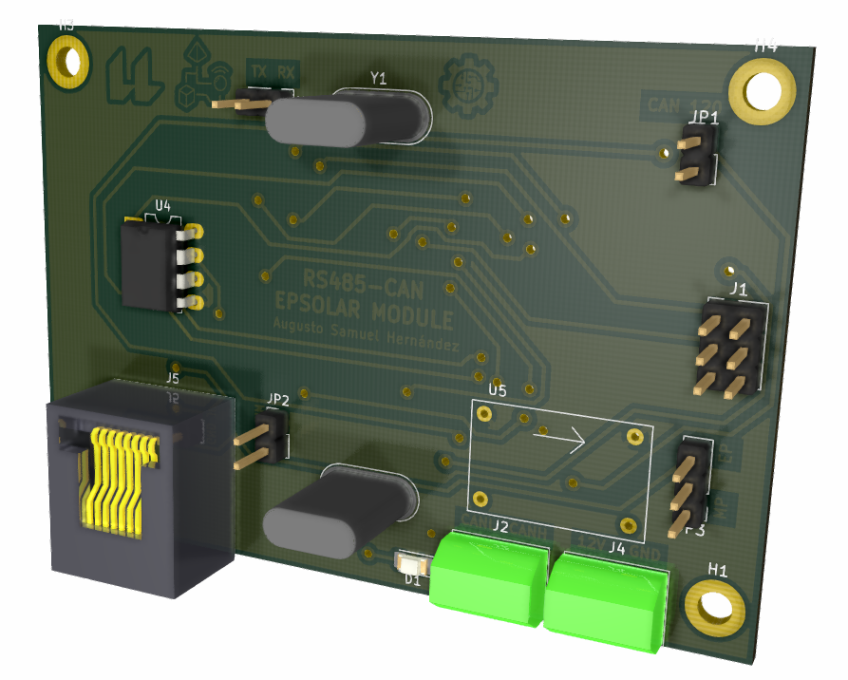
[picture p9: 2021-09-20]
Diseno-Electronico/EPSolar-CAN/RENDER/render_0.png

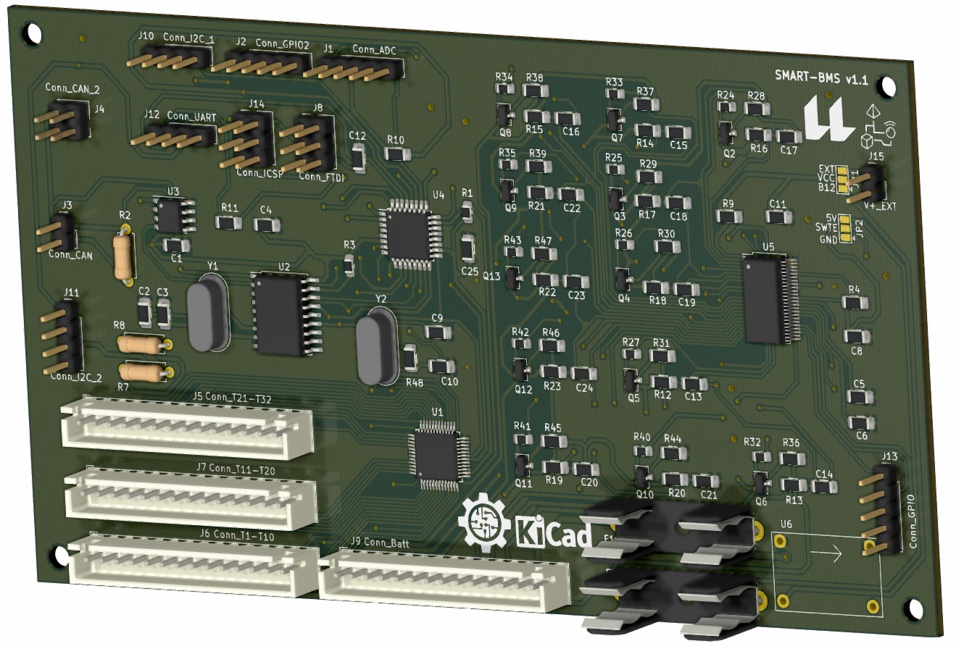
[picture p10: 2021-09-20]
Diseno-Electronico/SmartBMS/RENDER/render_3.jpg

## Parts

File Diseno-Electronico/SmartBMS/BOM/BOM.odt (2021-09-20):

BOM de PCB para BMS v1.1. Fecha 03/05/2021

Reference | Quantity | Value | Footprint
C1 C4 C11 | 3 | 100n | SmartBMS:R_1206_3216Metric
C10 | 1 | 12-22pF | SmartBMS:R_1206_3216Metric
C12 | 1 | 100nF | SmartBMS:R_1206_3216Metric
C17 C18 C19 C13 C14 C15 C16 C22 C23 C24 C20 C21 | 12 | 10n | SmartBMS:R_1206_3216Metric
C25 | 1 | 100nF | Resistor_SMD:R_1206_3216Metric
C3 C2 | 2 | 27pF | SmartBMS:R_1206_3216Metric
C8 C6 C5 | 3 | 1u | SmartBMS:R_1206_3216Metric
C9 | 1 | 12-22 pF | SmartBMS:R_1206_3216Metric
F1 | 1 | fuse 1A | Fuse:Fuseholder_Cylinder-5x20mm_Stelvio-Kontek_PTF78_Horizontal_Open
F2 | 1 | fuse 1 A | Fuse:Fuseholder_Cylinder-5x20mm_Stelvio-Kontek_PTF78_Horizontal_Open
H1 H2 H3 H4 | 4 | MountingHole | MountingHole:MountingHole_3.2mm_M3
J1 | 1 | Conn_ADC | SmartBMS:PinHeader_1x05_P2.54mm_Vertical
J10 | 1 | Conn_I2C_1 | SmartBMS:PinHeader_1x04_P2.54mm_Vertical
J11 | 1 | Conn_I2C_2 | SmartBMS:PinHeader_1x04_P2.54mm_Vertical
J12 | 1 | Conn_UART | SmartBMS:PinHeader_1x04_P2.54mm_Vertical
J13 | 1 | Conn_GPIO | SmartBMS:PinHeader_1x05_P2.54mm_Vertical
J14 | 1 | Conn_ICSP | SmartBMS:PinHeader_2x03_P2.54mm_Vertical
J15 | 1 | V+_EXT | SmartBMS:PinHeader_1x02_P2.54mm_Vertical
J2 | 1 | Conn_GPIO2 | SmartBMS:PinHeader_1x05_P2.54mm_Vertical
J3 | 1 | Conn_CAN | SmartBMS:PinHeader_1x02_P2.54mm_Vertical
J4 | 1 | Conn_CAN_2 | Connector_PinSocket_2.54mm:PinSocket_2x02_P2.54mm_Vertical
J5 | 1 | Conn_T21-T32 | SmartBMS:JST_XH_B14B-XH-A_1x14_P2.50mm_Vertical
J6 | 1 | Conn_T1-T10 | SmartBMS:JST_XH_B14B-XH-A_1x14_P2.50mm_Vertical
J7 | 1 | Conn_T11-T20 | SmartBMS:JST_XH_B14B-XH-A_1x14_P2.50mm_Vertical
J8 | 1 | Conn_FTDI | SmartBMS:PinHeader_2x03_P2.54mm_Vertical
J9 | 1 | Conn_Batt | SmartBMS:JST_XH_B14B-XH-A_1x14_P2.50mm_Vertical
JP1 JP2 | 2 | Jumper_3_Open | Jumper:SolderJumper-3_P1.3mm_Open_Pad1.0x1.5mm

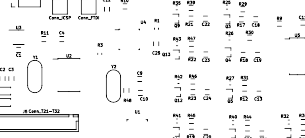
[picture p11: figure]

Q2 Q3 Q4 Q5 Q10 Q7 Q6 Q13 Q9 Q8 Q11 Q12 | 12 | BSS308PE | Package_TO_SOT_SMD:SOT-23
R1 | 1 | 10K | Resistor_SMD:R_0805_2012Metric_Pad1.15x1.40mm_HandSolder
R10 | 1 | 10k | SmartBMS:R_1206_3216Metric
R11 | 1 | 1k | SmartBMS:R_1206_3216Metric
R24 R25 R26 R27 R40 R33 R32 R43 R35 R34 R41 R42 | 12 | 1k | Resistor_SMD:R_0805_2012Metric_Pad1.15x1.40mm_HandSolder
R28 R29 R30 R31 R44 R37 R36 R47 R39 R38 R45 R46 | 12 | 10R, 2W | SmartBMS:R_1206_3216Metric
R3 | 1 | 10k | Resistor_SMD:R_0805_2012Metric_Pad1.15x1.40mm_HandSolder
R4 | 1 | 5k | Resistor_SMD:R_1206_3216Metric_Pad1.42x1.75mm_HandSolder
R48 | 1 | 1M | Resistor_SMD:R_1206_3216Metric
R7 R8 R2 | 3 | 120R | Resistor_THT:R_Axial_DIN0207_L6.3mm_D2.5mm_P7.62mm_Horizontal
R9 R16 R17 R18 R12 R13 R14 R15 R21 R22 R23 R19 R20 | 13 | 100R | SmartBMS:R_1206_3216Metric
U1 | 1 | ADG731 | Package_QFP:TQFP-48_7x7mm_P0.5mm
U2 | 1 | MCP2515-xSO | Package_SO:SOIC-18W_7.5x11.6mm_P1.27mm
U3 | 1 | TJA1050T | Package_SO:SOIC-8_3.9x4.9mm_P1.27mm
U4 | 1 | ATmega328P-PU | SmartBMS:TQFP-32_7x7mm_P0.8mm
U5 | 1 | LTC6804-2 | SmartBMS:SSOP-48_7.5x15.9mm_P0.635mm
U6 | 1 | MP2307 | SmartBMS:MP2307
Y1 | 1 | 8MHz | SmartBMS:Crystal_HC49-4H_Vertical
Y2 | 1 | 16MHz | SmartBMS:Crystal_HC49-4H_Vertical

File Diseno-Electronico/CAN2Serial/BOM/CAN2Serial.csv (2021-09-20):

Reference | Quantity | Value | Footprint | Datasheet
C1 C2 | 2 | 100n | Capacitor_SMD:C_1206_3216Metric_Pad1.33x1.80mm_HandSolder | ~
C5 C6 C4 C3 | 4 | 22pF | Capacitor_SMD:C_1206_3216Metric_Pad1.33x1.80mm_HandSolder | ~
C7 | 1 | 100nF | Capacitor_SMD:C_1206_3216Metric_Pad1.33x1.80mm_HandSolder | ~
C8 C11 C10 C12 C9 C13 | 6 | 1uF | Capacitor_THT:CP_Radial_D4.0mm_P1.50mm | ~
H1 H2 H3 H4 | 4 | MountingHole_Pad-Mechanical | MountingHole:MountingHole_3.2mm_M3_DIN965_Pad
J1 | 1 | Conn_ICSP | Connector_PinHeader_2.54mm:PinHeader_2x03_P2.54mm_Vertical | ~
J2 | 1 | CAN_conn | TerminalBlock:TerminalBlock_bornier-2_P5.08mm | ~
J3 | 1 | Serial_TTL_Conn | TerminalBlock:TerminalBlock_bornier-2_P5.08mm | ~
J4 | 1 | 232_Conn | TerminalBlock:TerminalBlock_bornier-2_P5.08mm | ~
J5 | 1 | GPIO_Conn | Connector_PinHeader_2.54mm:PinHeader_1x02_P2.54mm_Vertical | ~
J6 | 1 | Power_conn | TerminalBlock:TerminalBlock_bornier-2_P5.08mm | ~
JP1 | 1 | 232_EN | Jumper:SolderJumper-2_P1.3mm_Open_RoundedPad1.0x1.5mm | ~
JP2 | 1 | EndBus_R_Jumper | Jumper:SolderJumper-2_P1.3mm_Open_RoundedPad1.0x1.5mm | ~
R2 R3 | 2 | 220R | Resistor_SMD:R_1206_3216Metric_Pad1.30x1.75mm_HandSolder | ~
R4 R1 | 2 | 1M | Resistor_SMD:R_1206_3216Metric_Pad1.30x1.75mm_HandSolder | ~
R5 R6 | 2 | 10k | Resistor_SMD:R_0805_2012Metric_Pad1.20x1.40mm_HandSolder | ~
R7 | 1 | 120R | Resistor_SMD:R_0805_2012Metric_Pad1.20x1.40mm_HandSolder | ~
U1 | 1 | ATmega328P-PU-TQFP-Arduino | Package_QFP:TQFP-32_7x7mm_P0.8mm
U2 | 1 | MCP2515-xSO | Package_SO:SOIC-18W_7.5x11.6mm_P1.27mm | http://ww1.microchip.com/downloads/en/DeviceDoc/21801e.pdf
U3 | 1 | MAX232 | Package_DIP:DIP-16_W7.62mm_Socket | http://www.ti.com/lit/ds/symlink/max232.pdf
U4 | 1 | TJA1050T-SmartBMS | Package_SO:SOIC-8_3.9x4.9mm_P1.27mm
Y1 | 1 | 8MHz | Crystal:Crystal_HC49-U_Vertical | ~
Y2 | 1 | 16MHz | Crystal:Crystal_HC49-U_Vertical | ~

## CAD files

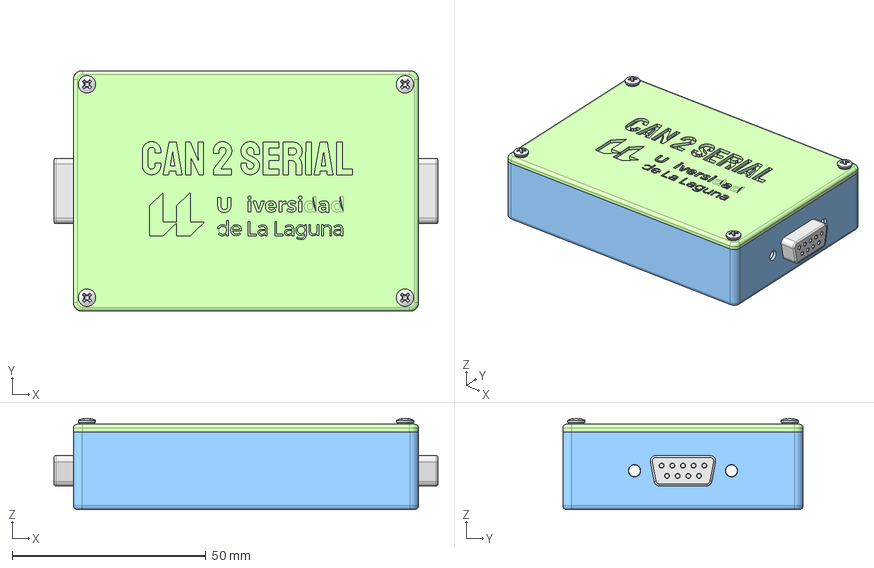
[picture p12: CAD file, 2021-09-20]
Diseno-Mecanico/Carcasa_Can2Serial.FCStd
99.0 x 62.0 x 23.5 mm
DB-9-CAN
DB-9
Tapa_con_logos
Carcasa_Fillet
M3x5-Screw003
M3x5-Screw002
M3x5-Screw
M3x5-Screw001
M2.5x5-Screw
M2.5x5-Screw001
M2.5x5-Screw002
M2.5x5-Screw003

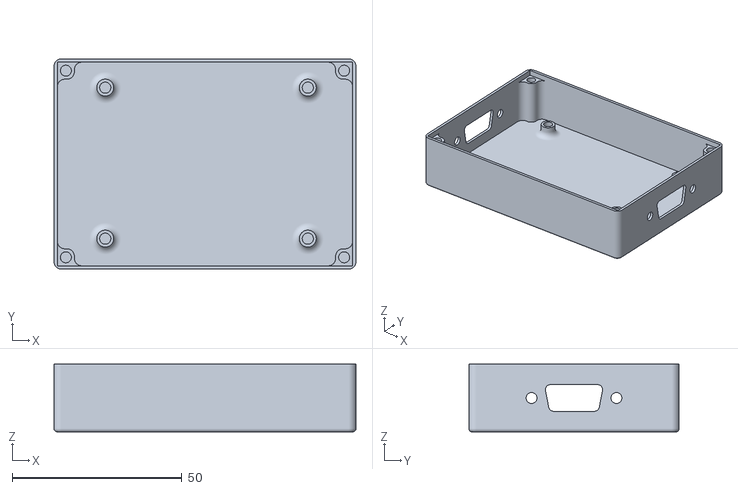
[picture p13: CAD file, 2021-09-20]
Diseno-Mecanico/STL/Carcasa_Can2Serial-Carcasa_Fillet.stl
89.0 x 62.0 x 20.0

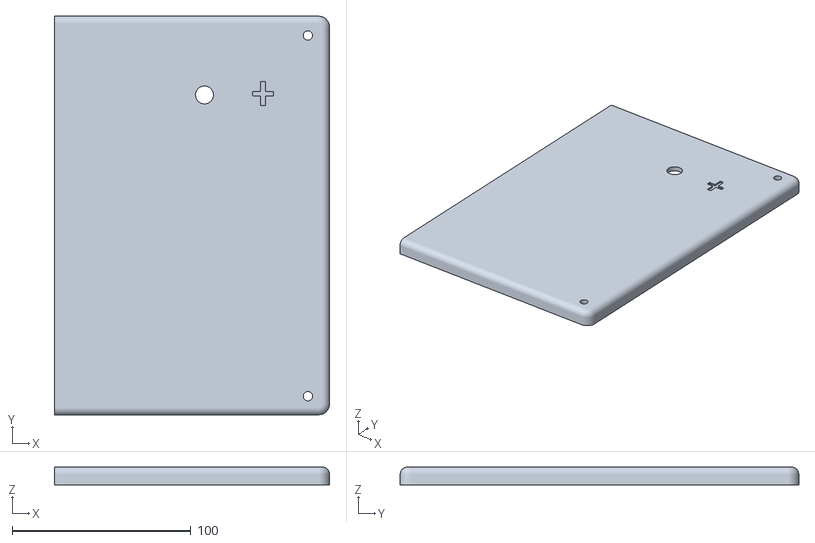
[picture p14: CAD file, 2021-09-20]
Diseno-Mecanico/STL/Caja_bateria_horizontal_10-Tapa_Drcha.stl
154.0 x 223.2 x 10.0

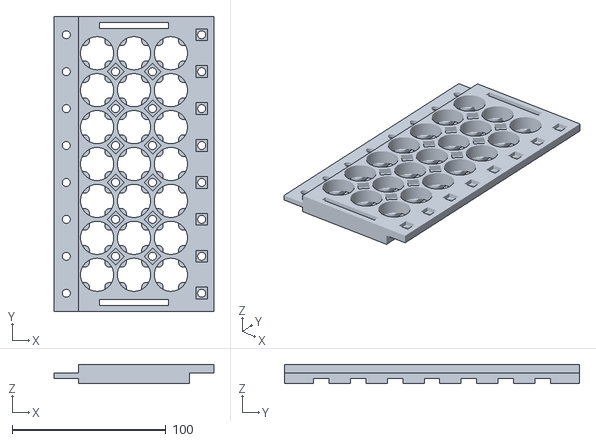
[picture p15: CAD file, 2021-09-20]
Diseno-Mecanico/STL/Caja_bateria_horizontal_10-Modulo_celda.stl
104.0 x 192.0 x 12.4

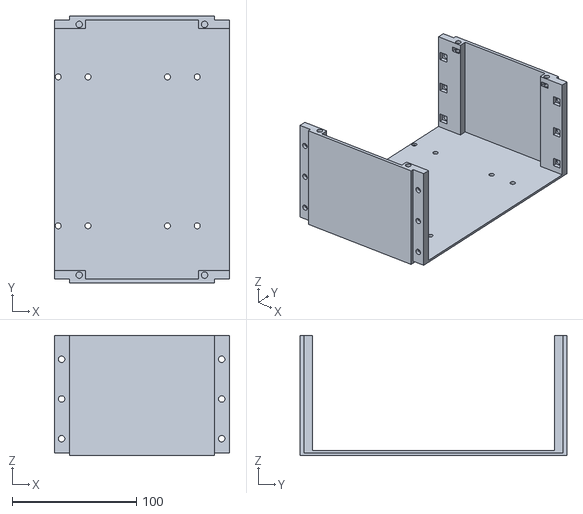
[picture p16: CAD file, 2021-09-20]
Diseno-Mecanico/STL/Caja_bateria_horizontal_10-Caja_Central_Fillet.stl
141.0 x 215.0 x 97.0

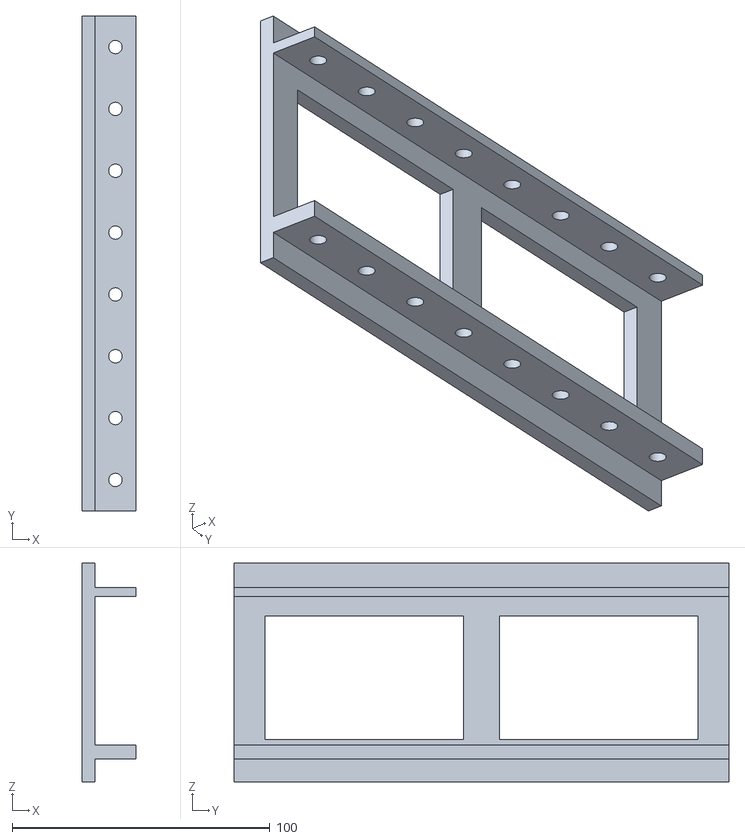
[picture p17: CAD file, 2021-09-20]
Diseno-Mecanico/STL/Caja_bateria_horizontal_10-Tapeta_Lateral_Izquierda.stl
21.0 x 192.0 x 85.0

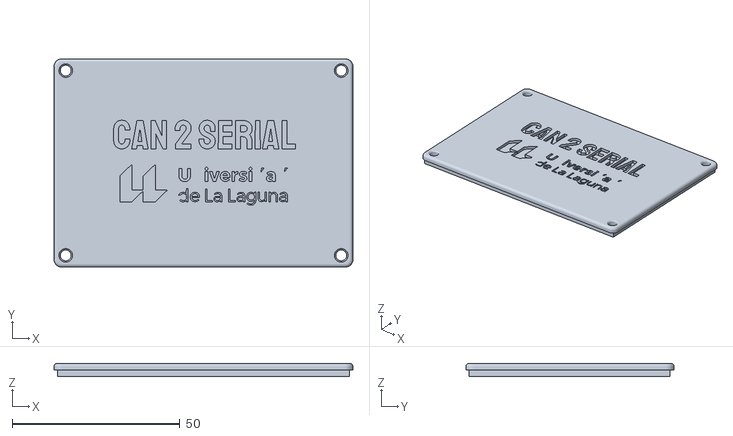
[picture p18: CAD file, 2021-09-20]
Diseno-Mecanico/STL/Carcasa_Can2Serial-Tapa_con_logos.stl
89.0 x 62.0 x 4.00

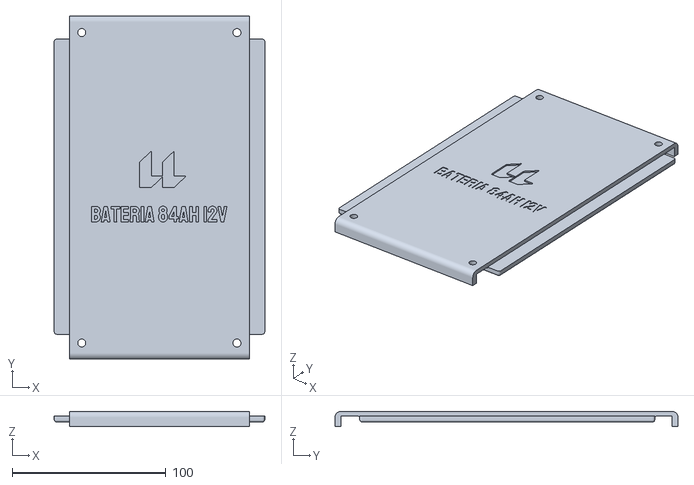
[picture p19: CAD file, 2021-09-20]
Diseno-Mecanico/STL/Caja_bateria_horizontal_10-Tapa_Central.stl
137.0 x 223.2 x 10.0

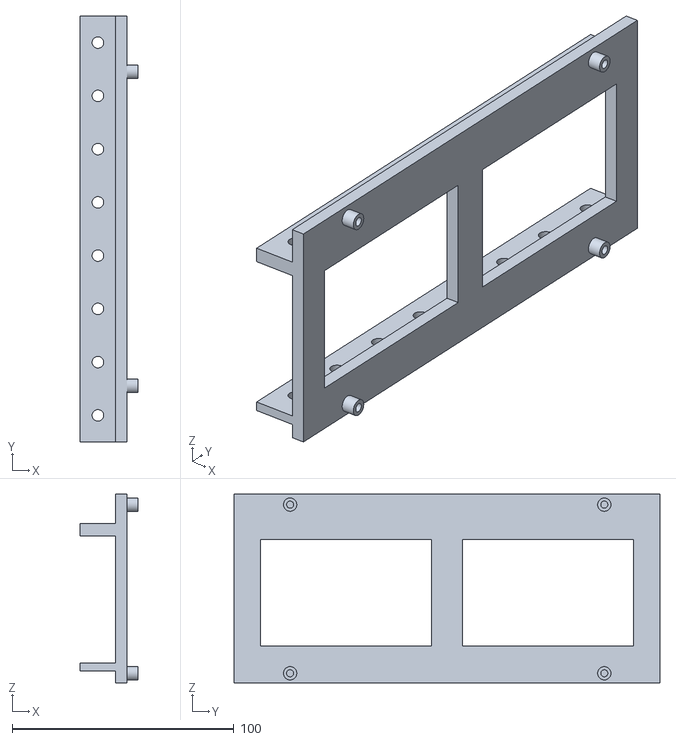
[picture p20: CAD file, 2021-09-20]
Diseno-Mecanico/STL/Caja_bateria_horizontal_10-Tapeta_Lateral_Derecha_PCB.stl
26.0 x 192.0 x 85.0

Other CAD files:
Diseno-Mecanico/STL/Caja_bateria_horizontal_10-Tapa_Izda.stl

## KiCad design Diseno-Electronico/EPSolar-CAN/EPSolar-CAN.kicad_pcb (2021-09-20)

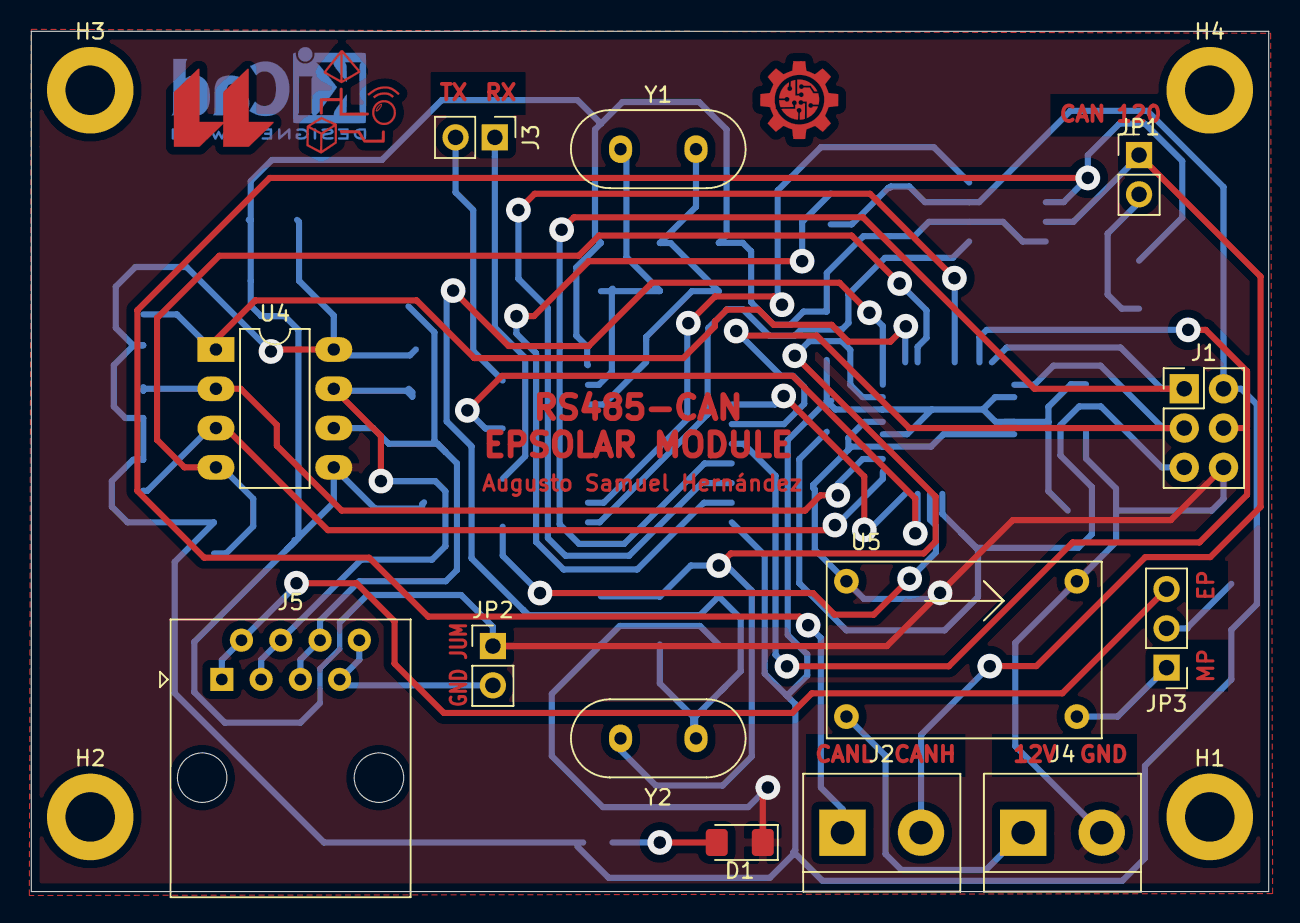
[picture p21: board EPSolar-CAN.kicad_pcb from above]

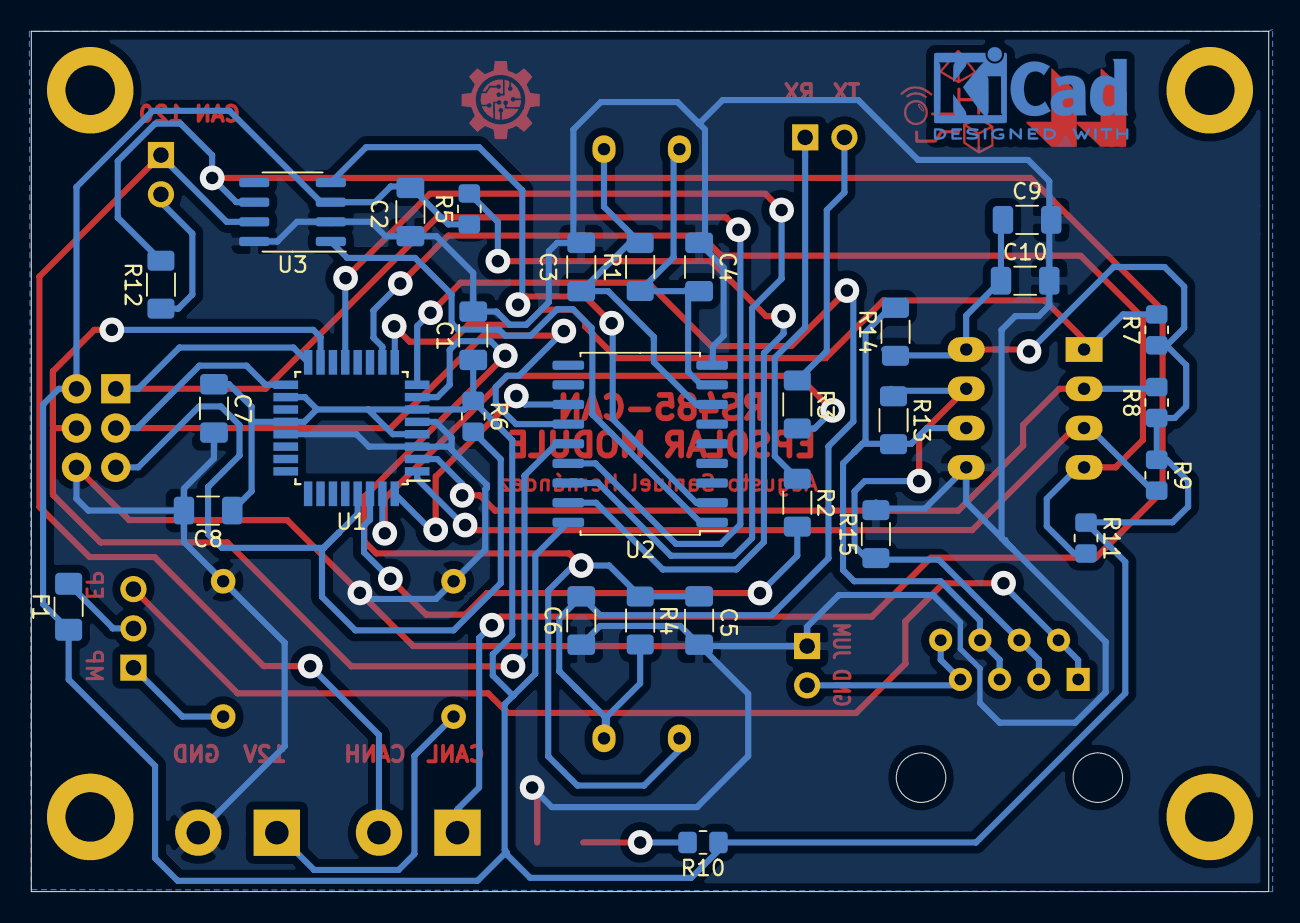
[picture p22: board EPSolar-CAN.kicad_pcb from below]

Board: 2 copper layers, 80.0 x 55.6 mm, 46 parts (29 on the bottom side), 34 nets.

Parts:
C1, C2: 100n; C_1206_3216Metric_Pad1.33x1.80mm_HandSolder
C3, C4, C5, C6: 22pF; C_1206_3216Metric_Pad1.33x1.80mm_HandSolder
C7: 100nF; C_1206_3216Metric_Pad1.33x1.80mm_HandSolder
C8: 1uF; C_1206_3216Metric_Pad1.33x1.80mm_HandSolder
C9: 10uF; C_1206_3216Metric_Pad1.33x1.80mm_HandSolder
C10: 0.1uF; C_1206_3216Metric_Pad1.33x1.80mm_HandSolder
D1: LED; LED_1206_3216Metric_Pad1.42x1.75mm_HandSolder
F1: Fuse; Fuse_1206_3216Metric_Pad1.42x1.75mm_HandSolder
H1, H2, H3, H4: MountingHole_Pad-Mechanical; MountingHole_3.2mm_M3_DIN965_Pad
J1: Conn_ICSP; PinHeader_2x03_P2.54mm_Vertical
J2: CAN_conn; TerminalBlock_bornier-2_P5.08mm
J3: Serial_TTL_Conn; PinHeader_1x02_P2.54mm_Vertical
J4: Power_Conn; TerminalBlock_bornier-2_P5.08mm
J5: RJ45; RJ45_Amphenol_54602-x08_Horizontal
JP1: EndBus_R_Jumper; PinHeader_1x02_P2.54mm_Vertical
JP2: Jumper_GND_RS485; PinHeader_1x02_P2.54mm_Vertical
JP3: Jumper_3_Open; PinHeader_1x03_P2.54mm_Vertical
R1, R4: 1M; R_1206_3216Metric_Pad1.30x1.75mm_HandSolder
R2, R3: 220R; R_1206_3216Metric_Pad1.30x1.75mm_HandSolder
R5, R6, R7, R8, R9, R11: 10k; R_0805_2012Metric_Pad1.20x1.40mm_HandSolder
R10: 1k; R_0805_2012Metric_Pad1.20x1.40mm_HandSolder
R12, R13: 120R; R_1206_3216Metric_Pad1.30x1.75mm_HandSolder
R14, R15: 20k; R_1206_3216Metric_Pad1.30x1.75mm_HandSolder
U1: ATmega328P-PU-TQFP-Arduino; TQFP-32_7x7mm_P0.8mm
U2: MCP2515-xSO; SOIC-18W_7.5x11.6mm_P1.27mm
U3: TJA1050T-SmartBMS; SOIC-8_3.9x4.9mm_P1.27mm
U4: MAX485E; DIP-8_W7.62mm_LongPads
U5: MP2307
Y1: 8MHz; Crystal_HC49-U_Vertical
Y2: 16MHz; Crystal_HC49-U_Vertical

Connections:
5V-EPSOLAR: J5.1, J5.2, JP3.3
5V-MP2307: JP3.1, U5.3
5V-PreFuse: F1.2, JP3.2
+5V: C1.1, C2.1, C7.1, C8.1, C9.1, C10.1, F1.1, J1.2, R5.1, R6.1, R7.1, R8.1, R9.1, R10.1, R11.1, R14.1, U1.4, U1.6, U1.18, U1.20, U2.18, U3.3, U4.8
+12V: J4.1, U5.1
/MISO: J1.1, U1.16, U2.15
/MOSI: J1.4, U1.15, U2.14
/RESET: J1.5, R6.2, U1.29
/SCK: J1.3, U1.17, U2.13
/SS_MCP: U1.13, U2.16
A: J5.5, J5.6, R13.2, R14.2, U4.6
B: J5.3, J5.4, R13.1, R15.1, U4.7
CANH: J2.2, JP1.1, U3.7
CANL: J2.1, R12.2, U3.6
DE-485: R9.2, U1.1, U4.3
DI-485: R11.2, U1.10, U4.4
GND: C1.2, C2.2, C3.1, C4.1, C5.1, C6.1, C7.2, C8.2, C9.2, C10.2, D1.1, J1.6, J4.2, JP2.1, R15.2, U1.3, U1.5, U1.21, U2.9, U3.2, U3.8, U4.5, U5.2, U5.4
GND-EPSOLAR: J5.7, J5.8, JP2.2
MCP_INT: U1.32, U2.12
unnamed: C3.2, R1.2, U2.7, Y1.2
unnamed: C4.2, R1.1, U2.8, Y1.1
unnamed: C5.2, R4.1, U1.7, Y2.1
unnamed: C6.2, R4.2, U1.8, Y2.2
unnamed: D1.2, R10.2
unnamed: JP1.2, R12.1
unnamed: R2.2, U1.30
unnamed: R3.2, U1.31
unnamed: R5.2, U2.17
RE-485: R8.2, U1.2, U4.2
RO-485: R7.2, U1.9, U4.1
RXCAN: U2.2, U3.4
RX_TTL: J3.1, R2.1
TXCAN: U2.1, U3.1
TX_TTL: J3.2, R3.1

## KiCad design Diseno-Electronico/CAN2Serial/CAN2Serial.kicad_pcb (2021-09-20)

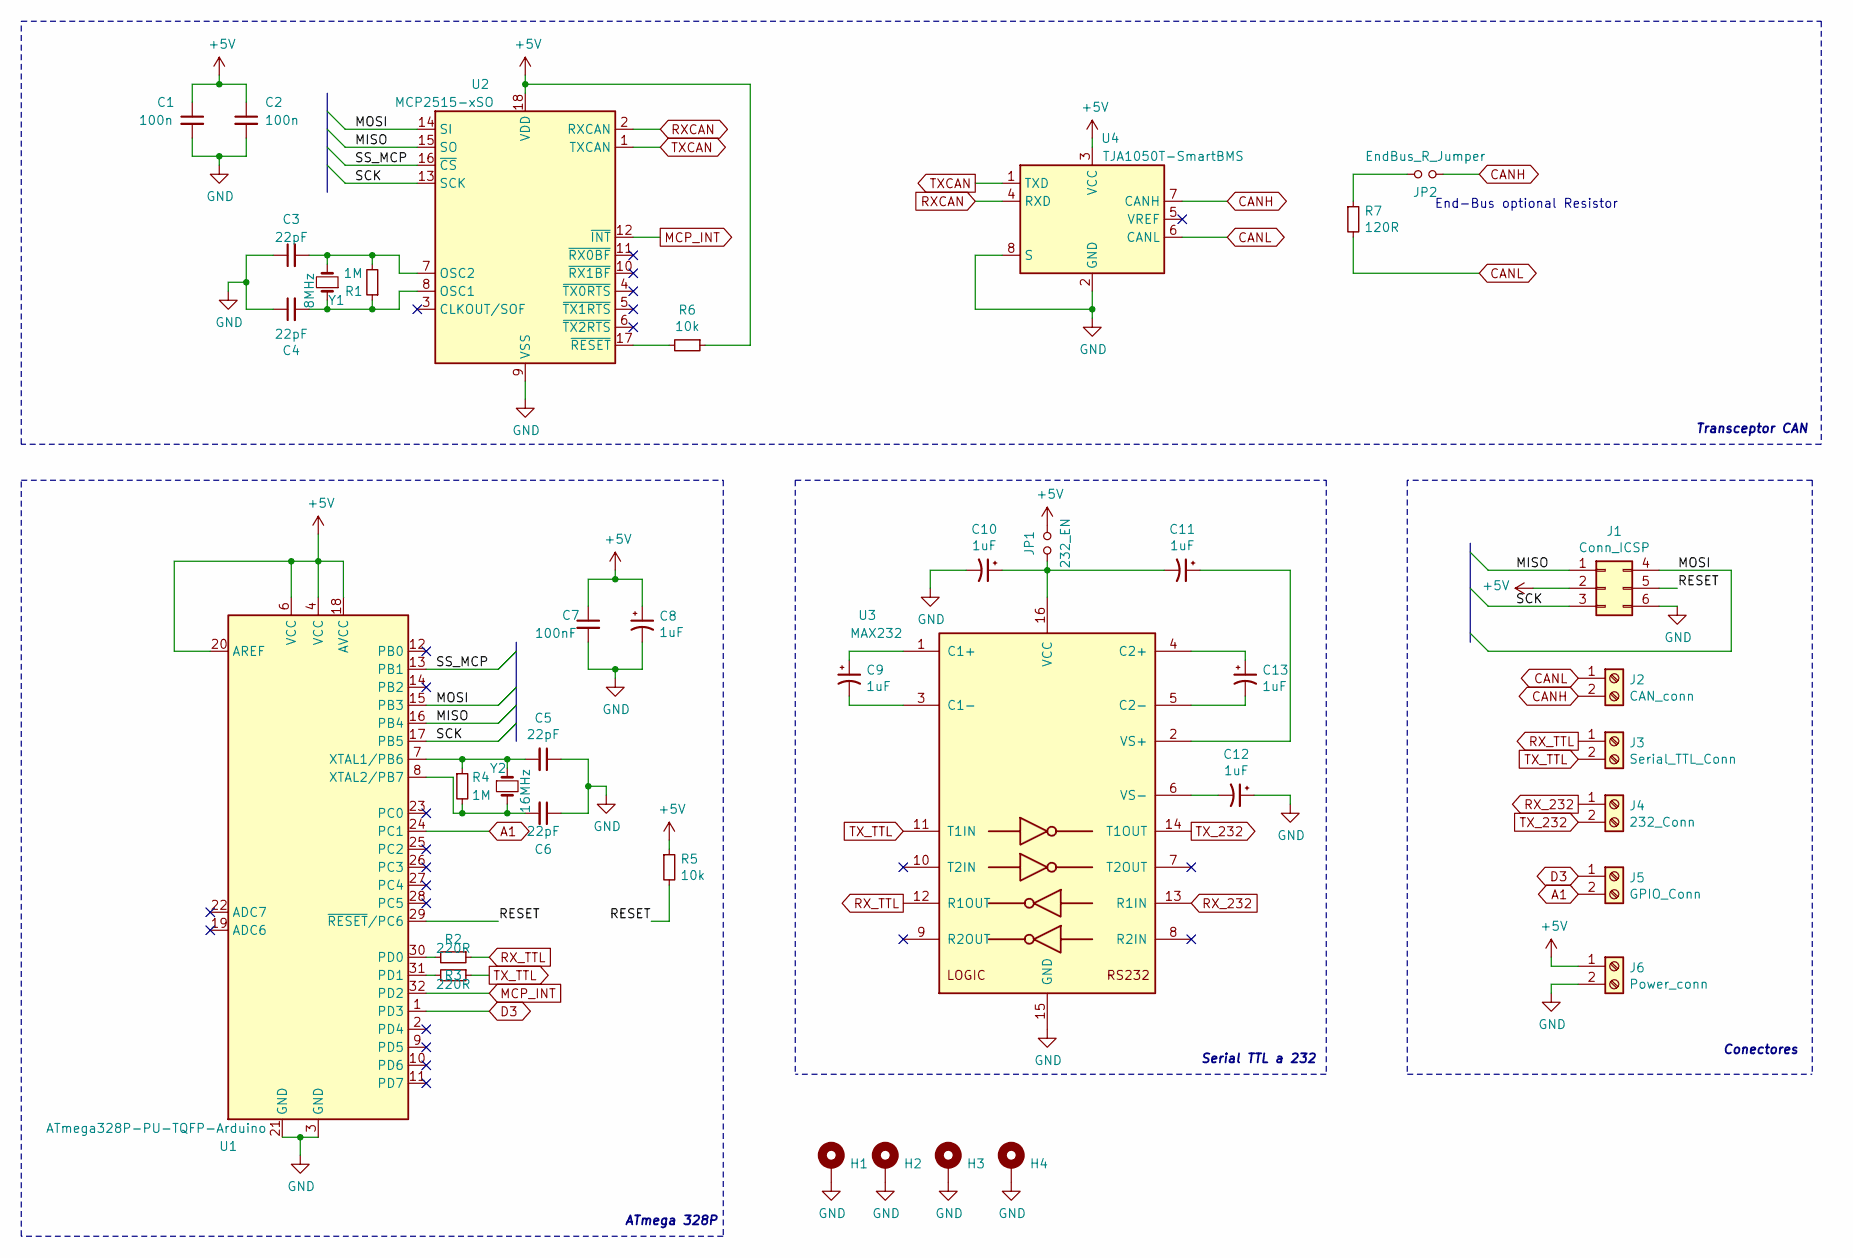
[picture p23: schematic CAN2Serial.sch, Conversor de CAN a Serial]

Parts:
C1, C2: 100n; C_1206_3216Metric_Pad1.33x1.80mm_HandSolder
C3, C4, C5, C6: 22pF; C_1206_3216Metric_Pad1.33x1.80mm_HandSolder
C7: 100nF; C_1206_3216Metric_Pad1.33x1.80mm_HandSolder
C8, C9, C10, C11, C12, C13: 1uF; CP_Radial_D4.0mm_P1.50mm
H1, H2, H3, H4: MountingHole_Pad-Mechanical; MountingHole_3.2mm_M3_DIN965_Pad
J1: Conn_ICSP; PinHeader_2x03_P2.54mm_Vertical
J2: CAN_conn; TerminalBlock_bornier-2_P5.08mm
J3: Serial_TTL_Conn; TerminalBlock_bornier-2_P5.08mm
J4: 232_Conn; TerminalBlock_bornier-2_P5.08mm
J5: GPIO_Conn; PinHeader_1x02_P2.54mm_Vertical
J6: Power_conn; TerminalBlock_bornier-2_P5.08mm
JP1: 232_EN; SolderJumper-2_P1.3mm_Open_RoundedPad1.0x1.5mm
JP2: EndBus_R_Jumper; SolderJumper-2_P1.3mm_Open_RoundedPad1.0x1.5mm
R1, R4: 1M; R_1206_3216Metric_Pad1.30x1.75mm_HandSolder
R2, R3: 220R; R_1206_3216Metric_Pad1.30x1.75mm_HandSolder
R5, R6: 10k; R_0805_2012Metric_Pad1.20x1.40mm_HandSolder
R7: 120R; R_0805_2012Metric_Pad1.20x1.40mm_HandSolder
U1: ATmega328P-PU-TQFP-Arduino; TQFP-32_7x7mm_P0.8mm
U2: MCP2515-xSO; SOIC-18W_7.5x11.6mm_P1.27mm
U3: MAX232; DIP-16_W7.62mm_Socket
U4: TJA1050T-SmartBMS; SOIC-8_3.9x4.9mm_P1.27mm
Y1: 8MHz; Crystal_HC49-U_Vertical
Y2: 16MHz; Crystal_HC49-U_Vertical

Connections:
+5V: C1.1, C2.1, C7.1, C8.1, J1.2, J6.1, JP1.2, R5.1, R6.1, U1.4 (VCC), U1.6 (VCC), U1.18 (AVCC), U1.20 (AREF), U2.18 (VDD), U4.3 (VCC); also elsewhere on the board
/MISO: J1.1, U1.16 (PB4), U2.15 (SO)
/MOSI: J1.4, U1.15 (PB3), U2.14 (SI)
/RESET: J1.5, R5.2, U1.29 (~RESET~/PC6)
/SCK: J1.3, U1.17 (PB5), U2.13 (SCK)
/SS_MCP: U1.13 (PB1), U2.16 (~CS)
A1: J5.2, U1.24 (PC1)
CANH: J2.2, JP2.1, U4.7 (CANH); also elsewhere on the board
CANL: J2.1, R7.2, U4.6 (CANL); also elsewhere on the board
D3: J5.1, U1.1 (PD3)
GND: C1.2, C2.2, C3.1, C4.1, C5.1, C6.1, C7.2, C8.2, C10.2, C12.1, H1.1, H2.1, H3.1, H4.1, J1.6, J6.2, U1.3 (GND), U1.5 (GND), U1.21 (GND), U2.9 (VSS), U3.15 (GND), U4.2 (GND), U4.8 (S); also elsewhere on the board
MCP_INT: U1.32 (PD2), U2.12 (~INT)
unnamed: C3.2, R1.2, U2.7 (OSC2), Y1.2
unnamed: C4.2, R1.1, U2.8 (OSC1), Y1.1
unnamed: C5.2, R4.1, U1.7 (XTAL1/PB6), Y2.1
unnamed: C6.2, R4.2, U1.8 (XTAL2/PB7), Y2.2
unnamed: C9.1, U3.1 (C1+)
unnamed: C9.2, U3.3 (C1-)
unnamed: C10.1, C11.2, JP1.1, U3.16 (VCC)
unnamed: C11.1, U3.2 (VS+)
unnamed: C12.2, U3.6 (VS-)
unnamed: C13.1, U3.4 (C2+)
unnamed: C13.2, U3.5 (C2-)
unnamed: JP2.2, R7.1
unnamed: R2.2, U1.30 (PD0)
unnamed: R3.2, U1.31 (PD1)
unnamed: R6.2, U2.17 (~RESET)
RXCAN: U2.2 (RXCAN), U4.4 (RXD); also elsewhere on the board
RX_232: J4.1, U3.13 (R1IN)
RX_TTL: J3.1, R2.1, U3.12 (R1OUT)
TXCAN: U2.1 (TXCAN), U4.1 (TXD); also elsewhere on the board
TX_232: J4.2, U3.14 (T1OUT)
TX_TTL: J3.2, R3.1, U3.11 (T1IN)

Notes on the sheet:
End-Bus optional Resistor
Transceptor CAN
Conectores
Serial TTL a 232
ATmega 328P

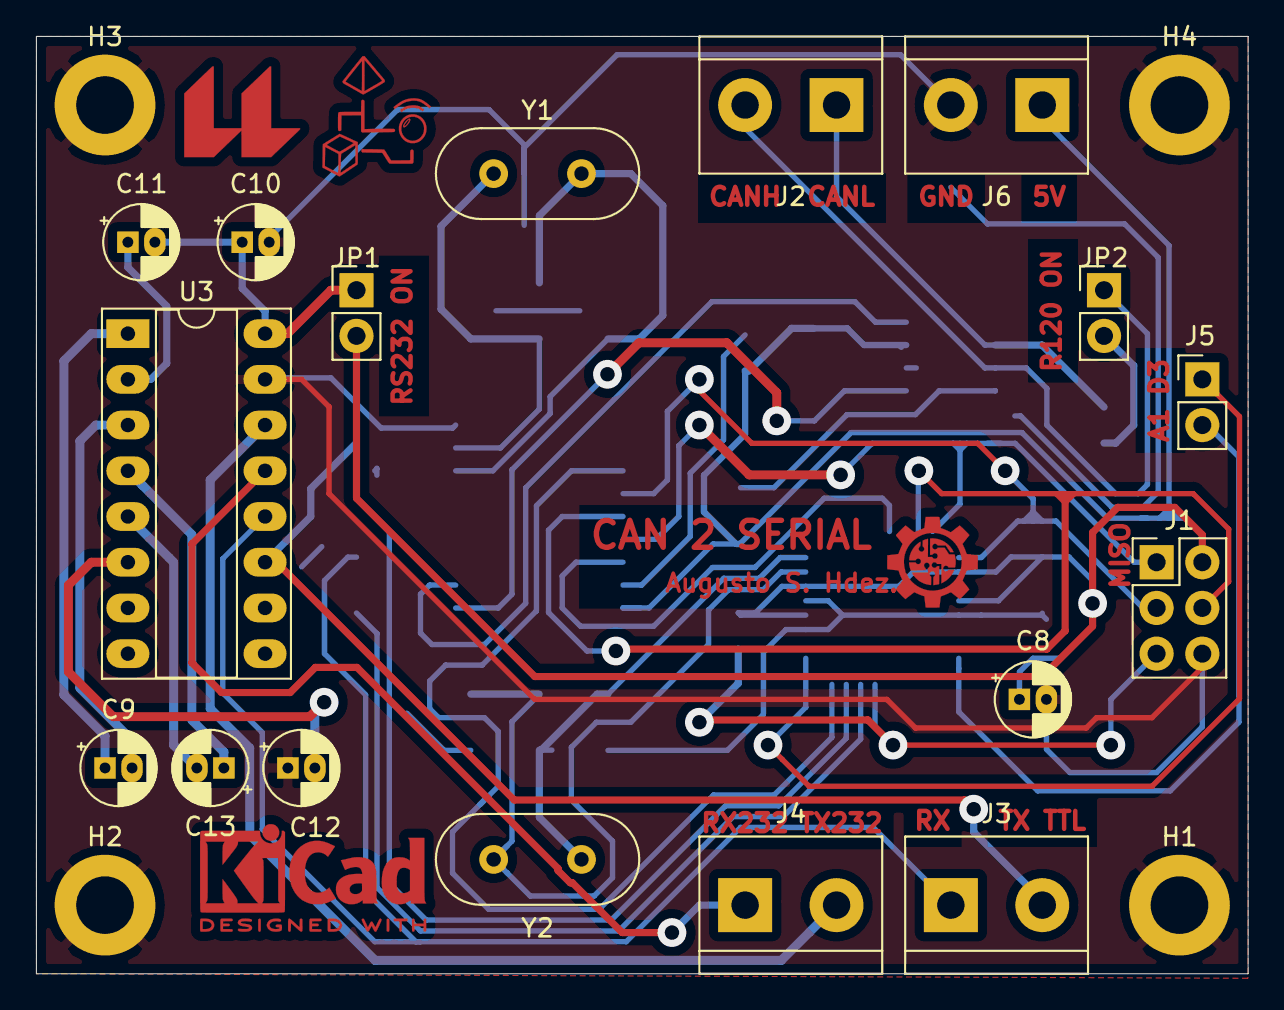
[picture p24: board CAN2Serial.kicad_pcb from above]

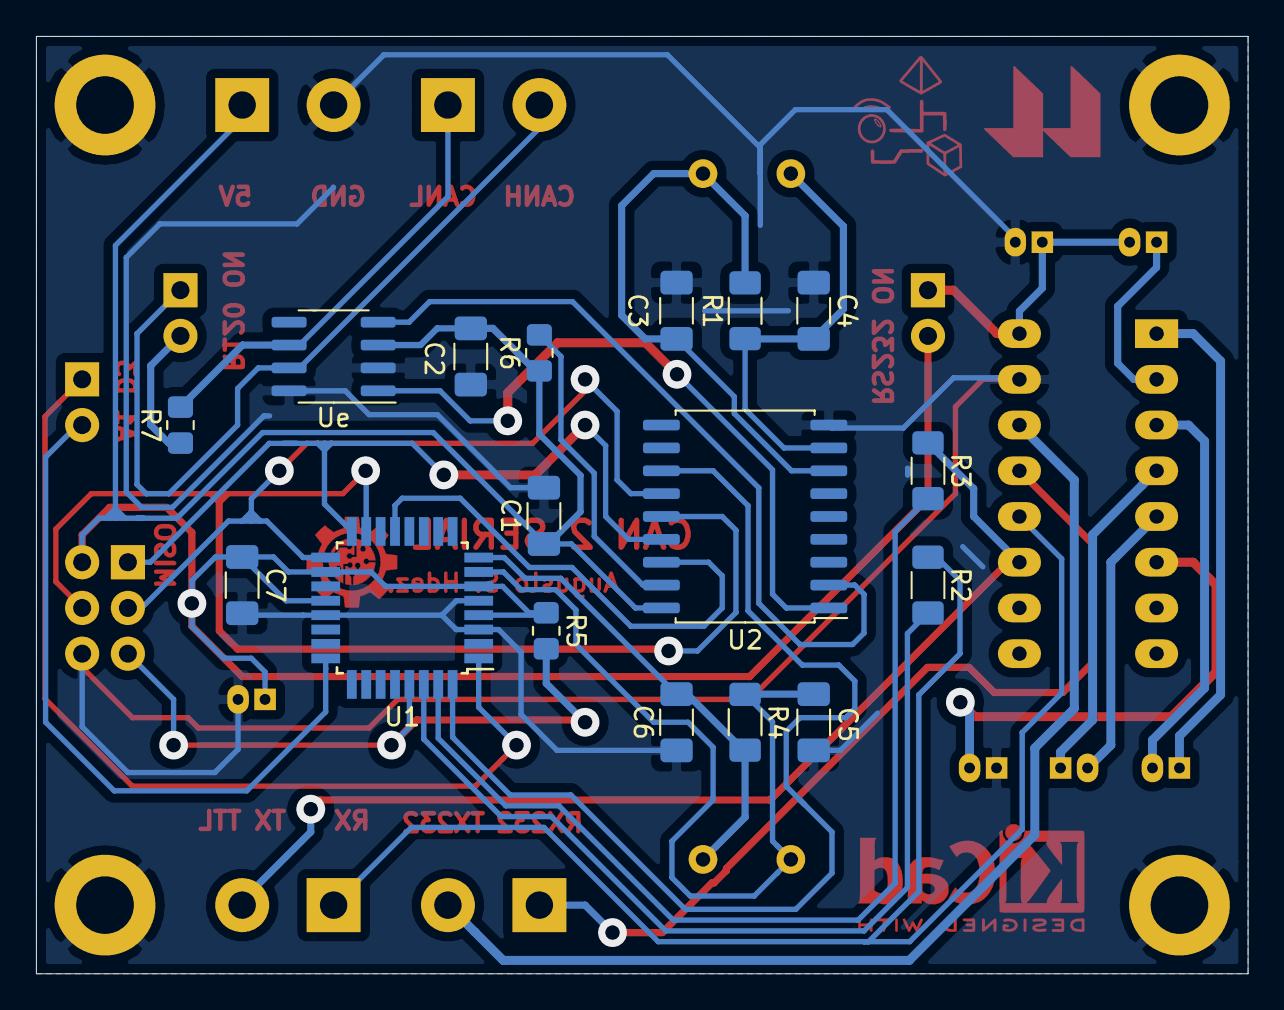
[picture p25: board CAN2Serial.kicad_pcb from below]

Board: 2 copper layers, 67.3 x 52.1 mm, 38 parts (17 on the bottom side), 33 nets.

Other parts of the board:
Ue: TJA1050T-SmartBMS; SOIC-8_3.9x4.9mm_P1.27mm

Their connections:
+5V: Ue.3; also elsewhere on the board
CANH: Ue.7; also elsewhere on the board
CANL: Ue.6; also elsewhere on the board
GND: Ue.2, Ue.8; also elsewhere on the board
RXCAN: Ue.4; also elsewhere on the board
TXCAN: Ue.1; also elsewhere on the board

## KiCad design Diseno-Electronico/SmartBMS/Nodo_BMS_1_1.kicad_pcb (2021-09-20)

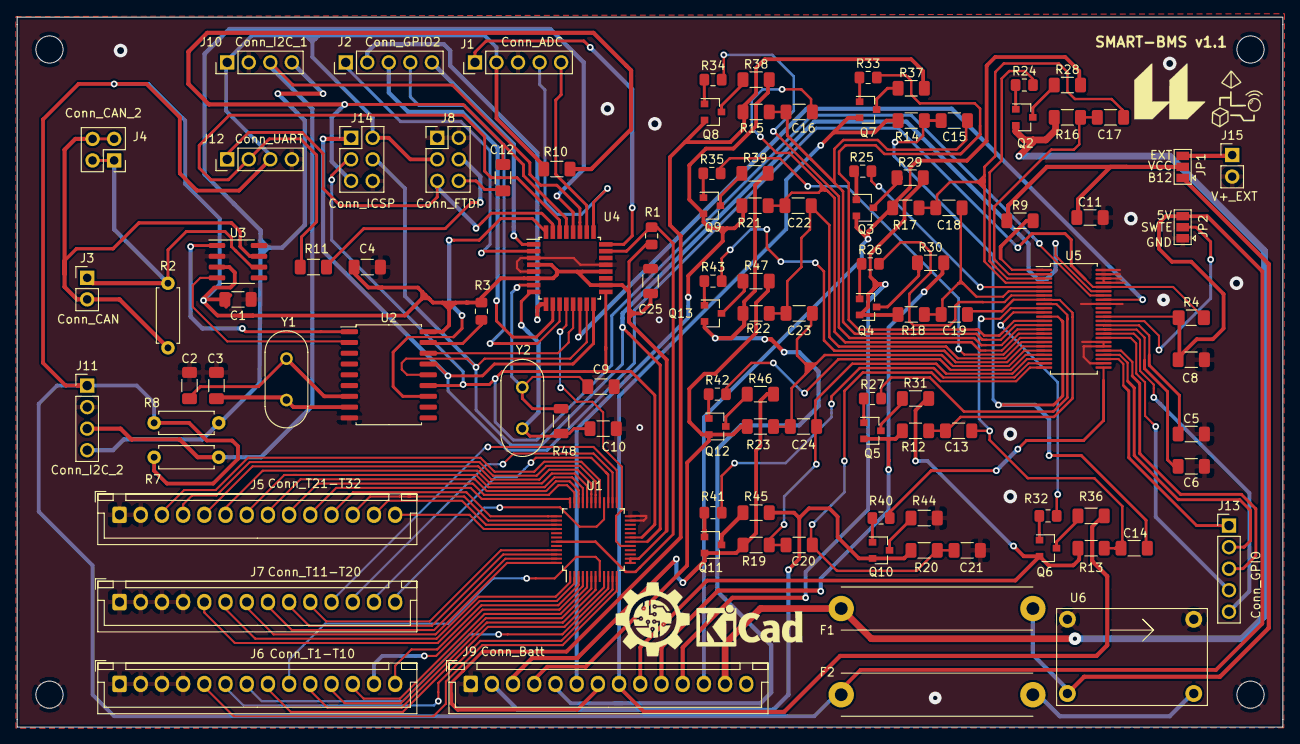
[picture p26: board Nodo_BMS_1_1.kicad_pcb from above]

Board: 2 copper layers, 149.2 x 83.7 mm, 113 parts (0 on the bottom side), 139 nets.

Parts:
C1, C4, C11: 100n; R_1206_3216Metric_Pad1.30x1.75mm_HandSolder
C2, C3: 27pF; R_1206_3216Metric_Pad1.30x1.75mm_HandSolder
C5, C6, C8: 1u; R_1206_3216Metric_Pad1.30x1.75mm_HandSolder
C9: 12-22 pF; R_1206_3216Metric_Pad1.30x1.75mm_HandSolder
C10: 12-22pF; R_1206_3216Metric_Pad1.30x1.75mm_HandSolder
C12: 100nF; R_1206_3216Metric_Pad1.30x1.75mm_HandSolder
C13, C14, C15, C16, C17, C18, C19, C20, C21, C22, C23, C24: 10n; R_1206_3216Metric_Pad1.30x1.75mm_HandSolder
C25: 100nF; R_1206_3216Metric
F1: fuse 1A; Fuseholder_Cylinder-5x20mm_Stelvio-Kontek_PTF78_Horizontal_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
F2: fuse 0,5 A; Fuseholder_Cylinder-5x20mm_Stelvio-Kontek_PTF78_Horizontal_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
H1, H2, H3, H4: MountingHole; MountingHole_3.2mm_M3
J1: Conn_ADC; PinHeader_1x05_P2.54mm_Vertical
J2: Conn_GPIO2; PinHeader_1x05_P2.54mm_Vertical
J3: Conn_CAN; PinHeader_1x02_P2.54mm_Vertical
J4: Conn_CAN_2; PinSocket_2x02_P2.54mm_Vertical
J5: Conn_T21-T32; JST_XH_B14B-XH-A_1x14_P2.50mm_Vertical
J6: Conn_T1-T10; JST_XH_B14B-XH-A_1x14_P2.50mm_Vertical
J7: Conn_T11-T20; JST_XH_B14B-XH-A_1x14_P2.50mm_Vertical
J8: Conn_FTDI; PinHeader_2x03_P2.54mm_Vertical
J9: Conn_Batt; JST_XH_B14B-XH-A_1x14_P2.50mm_Vertical
J10: Conn_I2C_1; PinHeader_1x04_P2.54mm_Vertical
J11: Conn_I2C_2; PinHeader_1x04_P2.54mm_Vertical
J12: Conn_UART; PinHeader_1x04_P2.54mm_Vertical
J13: Conn_GPIO; PinHeader_1x05_P2.54mm_Vertical
J14: Conn_ICSP; PinHeader_2x03_P2.54mm_Vertical
J15: V+_EXT; PinHeader_1x02_P2.54mm_Vertical
JP1, JP2: Jumper_3_Open; SolderJumper-3_P1.3mm_Open_Pad1.0x1.5mm
Q2, Q3, Q4, Q5, Q6, Q7, Q8, Q9, Q10, Q11, Q12, Q13: BSS308PE; SOT-23
R1: 10K; R_0805_2012Metric_Pad1.15x1.40mm_HandSolder
R2, R7, R8: 120R; R_Axial_DIN0207_L6.3mm_D2.5mm_P7.62mm_Horizontal
R3: 10k; R_0805_2012Metric_Pad1.15x1.40mm_HandSolder
R4: 5k; R_1206_3216Metric_Pad1.42x1.75mm_HandSolder
R9, R12, R13, R14, R15, R16, R17, R18, R19, R20, R21, R22, R23: 100R; R_1206_3216Metric_Pad1.30x1.75mm_HandSolder
R10: 10k; R_1206_3216Metric_Pad1.30x1.75mm_HandSolder
R11: 1k; R_1206_3216Metric_Pad1.30x1.75mm_HandSolder
R24, R25, R26, R27, R32, R33, R34, R35, R40, R41, R42, R43: 1k; R_0805_2012Metric_Pad1.15x1.40mm_HandSolder
R28, R29, R30, R31, R36, R37, R38, R39, R44, R45, R46, R47: 10R, 2W; R_1206_3216Metric_Pad1.30x1.75mm_HandSolder
R48: 1M; R_1206_3216Metric
U1: ADG731; TQFP-48_7x7mm_P0.5mm
U2: MCP2515-xSO; SOIC-18W_7.5x11.6mm_P1.27mm
U3: TJA1050T; SOIC-8_3.9x4.9mm_P1.27mm
U4: ATmega328P-PU; TQFP-32_7x7mm_P0.8mm
U5: LTC6804-2; SSOP-48_5.3x12.8mm_P0.5mm
U6: MP2307
Y1: 8MHz; Crystal_HC49-4H_Vertical
Y2: 16MHz; Crystal_HC49-4H_Vertical

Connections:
+5V: C1.1, C4.1, C8.1, C25.1, F2.1, J1.2, J8.3, J10.1, J11.1, J12.3, J14.2, JP2.3, R1.2, R3.1, R4.1, R7.1, R8.1, R10.1, U1.13, U1.14, U2.18, U3.3, U4.4, U4.6, U4.18, U4.20, U5.37
/B1: J9.2, Q10.2, R20.1, R45.2
/B2: J9.3, Q11.2, R19.1, R46.2
/B3: J9.4, Q12.2, R23.1, R47.2
/B4: J9.5, Q13.2, R22.1, R39.2
/B5: J9.6, Q9.2, R21.1, R38.2
/B6: J9.7, Q8.2, R15.1, R37.2
/B7: J9.8, Q7.2, R14.1, R36.2
/B8: J9.9, Q6.2, R13.1, R31.2
/B9: J9.10, Q5.2, R12.1, R30.2
/B10: J9.11, Q4.2, R18.1, R29.2
/B11: J9.12, Q3.2, R17.1, R28.2
/B12: F1.1, J9.13, Q2.2, R16.1
/C1: C20.2, C21.1, R20.2, U5.24
/C2: C20.1, C24.2, R19.2, U5.22
/C3: C23.2, C24.1, R23.2, U5.20
/C4: C22.2, C23.1, R22.2, U5.18
/C5: C16.2, C22.1, R21.2, U5.16
/C6: C15.2, C16.1, R15.2, U5.14
/C7: C14.2, C15.1, R14.2, U5.12
/C8: C13.2, C14.1, R13.2, U5.10
/C9: C13.1, C19.2, R12.2, U5.8
/C10: C18.2, C19.1, R18.2, U5.6
/C11: C17.2, C18.1, R17.2, U5.4
/C12: C17.1, R16.2, U5.2
/MISO: J14.1, R4.2, U2.15, U4.16, U5.44
/MOSI: J14.4, U1.18, U2.14, U4.15, U5.43
/RESET: C12.2, J14.5, R10.2, U4.29
/RTS: C12.1, J8.6
/S1: R40.2, U5.25
/S2: R41.2, U5.23
/S3: R42.2, U5.21
/S4: R43.2, U5.19
/S5: R35.2, U5.17
/S6: R34.2, U5.15
/S7: R33.2, U5.13
/S8: R32.2, U5.11
/S9: R27.2, U5.9
/S10: R26.2, U5.7
/S11: R25.2, U5.5
/S12: R24.2, U5.3
/SCK: J14.3, U1.19, U2.13, U4.17, U5.42
/SCL: J10.4, J11.4, R8.2, U4.28
/SDA: J10.3, J11.3, R7.2, U4.27
/SS_LTC: U4.14, U5.41
/SS_MCP: U2.16, U4.13
/SWTEN: JP2.2, U5.36
/SYNC_MUX: U1.17, U4.12
/TXD: J8.4, R11.1
/V+_EXT: J15.1, JP1.3
/VREF1: C5.1, U5.35
/VREF2: C6.1, U5.34
A1: J1.1, U4.24
A2: J1.4, U4.25
A3: J1.5, U4.26
CANH: J3.2, J4.2, J4.4, R2.1, U3.7
CANL: J3.1, J4.1, J4.3, R2.2, U3.6
D4: J2.1, U4.2
D5: J2.2, U4.9
D6: J2.3, U4.10
D7: J2.4, U4.11
GND: C1.2, C2.2, C3.2, C4.2, C5.2, C6.2, C8.2, C9.2, C10.2, C11.2, C21.2, C25.2, H1.1, H2.1, H3.1, H4.1, J1.3, J5.1, J5.2, J6.1, J6.2, J6.3, J6.4, J7.1, J7.2, J7.3, J7.4, J8.1, J8.2, J9.1, J10.2, J11.2, J12.4, J14.6, J15.2, JP2.1, R44.2, U1.23, U1.24, U2.9, U3.2, U3.8, U4.3, U4.5, U4.21, U5.26, U5.30, U5.31, U5.40, U5.45, U5.46, U5.47, U5.48, U6.2, U6.4
GPIO1: J13.1, U5.27
GPIO2: J13.2, U5.28
GPIO3: J13.3, U5.29
GPIO4: J13.4, U5.32
GPIO5: J13.5, U5.33
INT1: J2.5, U4.1
MCP_INT: U2.12, U4.32
NTC_ADC: R1.1, U1.43, U4.23
unnamed: C2.1, U2.7, Y1.1
unnamed: C3.1, U2.8, Y1.2
unnamed: C9.1, R48.1, U4.7, Y2.2
unnamed: C10.1, R48.2, U4.8, Y2.1
unnamed: F1.2, JP1.1, U6.1
unnamed: F2.2, U6.3
unnamed: Q2.1, R24.1
unnamed: Q2.3, R28.1
unnamed: Q3.1, R25.1
unnamed: Q3.3, R29.1
unnamed: Q4.1, R26.1
unnamed: Q4.3, R30.1
unnamed: Q5.1, R27.1
unnamed: Q5.3, R31.1
unnamed: Q6.1, R32.1
unnamed: Q6.3, R36.1
unnamed: Q7.1, R33.1
unnamed: Q7.3, R37.1
unnamed: Q8.1, R34.1
unnamed: Q8.3, R38.1
unnamed: Q9.1, R35.1
unnamed: Q9.3, R39.1
unnamed: Q10.1, R40.1
unnamed: Q10.3, R44.1
unnamed: Q11.1, R41.1
unnamed: Q11.3, R45.1
unnamed: Q12.1, R42.1
unnamed: Q12.3, R46.1
unnamed: Q13.1, R43.1
unnamed: Q13.3, R47.1
unnamed: R3.2, U2.17
unnamed: R9.2, U5.1
RX: J12.2, R11.2, U4.30
RXCAN: U2.2, U3.4
T1: J6.5, U1.12
T2: J6.6, U1.11
T3: J6.7, U1.10
T4: J6.8, U1.9
T5: J6.9, U1.8
T6: J6.10, U1.7
T7: J6.11, U1.6
T8: J6.12, U1.5
T9: J6.13, U1.4
T10: J6.14, U1.3
T11: J7.5, U1.2
T12: J7.6, U1.1
T13: J7.7, U1.48
T14: J7.8, U1.47
T15: J7.9, U1.46
T16: J7.10, U1.45
T17: J7.11, U1.25
T18: J7.12, U1.26
T19: J7.13, U1.27
T20: J7.14, U1.28
T21: J5.3, U1.29
T22: J5.4, U1.30
T23: J5.5, U1.31
T24: J5.6, U1.32
T25: J5.7, U1.33
T26: J5.8, U1.34
T27: J5.9, U1.35
T28: J5.10, U1.36
T29: J5.11, U1.37
T30: J5.12, U1.38
T31: J5.13, U1.39
T32: J5.14, U1.40
TX: J8.5, J12.1, U4.31
TXCAN: U2.1, U3.1
VCC: C11.1, JP1.2, R9.1

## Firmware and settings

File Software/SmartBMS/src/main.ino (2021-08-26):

/*
   AUTOR: AUGUSTO SAMUEL HERNÁNDEZ MARTÍN
   FECHA: 05/05/2021
   NOMBRE: SMART BMS
   VERSIÓN: V.1.0
   DESCRIPCIÓN: FIRMWARE DEL MICROCONTROLADOR ALOJADO EN LA PCB DEL CONFIGURADOR. SU FUNCIÓN ES CONFIGURAR EL BMS Y OBTENER SUS PARÁMETROS DESDE EL CAN BUS PARA DEVOLVERLOS POR SERIAL
*/
#include <Arduino.h>
#include <stdint.h>
#include "config.h"
#include "const.h"
#include "BMS_lib.h"
#include "ADG731_lib.h"
#include "mcp2515.h"


#include <LowPower.h>

MCP2515 mcp2515(9); //Se declara el objeto de la clase MCP2515


/*******************************************************
 * CAN STRUCT
 ******************************************************/
//Struct para almacenar mensaje CAN recibido de configuracion
struct can_frame can_msg;

//Struct para almacenar los mensajes CAN de la batería
struct can_frame canBatMsg1;
struct can_frame canBatMsg2;
struct can_frame canBatMsg3;

//Struct para almacenar los mensajes CAN de las Temperaturas
struct can_frame canTempMsg1;
struct can_frame canTempMsg2;
struct can_frame canTempMsg3;
struct can_frame canTempMsg4;

//Struct para almacenar el mensaje CAN de la corriente
struct can_frame canCurrentMsg;

struct can_frame warning; //Mensaje CAN de warning de baja tensión batería, batería en sobretensión o anomalía en Tª

struct can_frame canSOCMsg; //Mensaje CAN para el SOC

/********************************************************
 * BATTERY VALUES
 ********************************************************/
float UVBAT_THR = 12.00 ; //Tensión minima de la batería
float OVBAT_THR = 16.00 ; //Tensión maxima de la batería
float UV_THR = 1.0 ; //Tension minima de una celda
float OV_THR = 5.0; //Tension maxima de una celda
float MAX_VCELL_DIFF = 0.005; //Diferencia de tension maxima entre celdas
uint8_t TOTAL_CELL = 4; //Número de celdas totales
uint8_t NCELL_PARALLEL = 3; //Numero de celdas en paralelo
int16_t CURRENT_OFFSET = 0; //Offset del sensor de corriente (en mA)
uint8_t TSLEEP = 0; //tiempo de reposo entre ciclos

uint8_t BALANCING_TYPE = 0b11; //Tipo de balanceo. Bit0 balanceo durante carga. Bit1 balanceo durante descarga. Por defecto se activa el balanceo en carga y descarga.
bool force_bal_flag = false; //Flag que se activa cuando el balanceo se está forzando desde el programador. Con esto activo no se tiene en cuenta las condiciones de balanceo



/********************************************************
 * TEMPERATURE VALUES
 ********************************************************/
//Parametros de las NTC
uint8_t N_NTC = 32; //Numero de NTCs conectadas al BMS
float cell_temp [32]; //Array 1D con las temperaturas medidas


/********************************************************
 * ARRAYS
 ********************************************************/
uint16_t cell_codes[TOTAL_IC][12];//Array 2D de códigos de celda. Se indexan en forma de matriz con fila el IC que mide y columna la celda de la batería
/*
   Sigue el siguiente formado

  |  cell_codes[0][0]| cell_codes[0][1] |  cell_codes[0][2]|    .....     |  cell_codes[0][11]|  cell_codes[1][0] | cell_codes[1][1]|  .....   |
  |------------------|------------------|------------------|--------------|-------------------|-------------------|-----------------|----------|
  |IC1 Cell 1        |IC1 Cell 2        |IC1 Cell 3        |    .....     |  IC1 Cell 12      |IC2 Cell 1         |IC2 Cell 2       | .....    |
*/


uint8_t tx_cfg[TOTAL_IC][6];
/*
  El tx_cfg[][6] almacena los datos de configuración del LTC6804 que se van a escribir a los IC que están en Daisy Chain.
  La configuración de los LTC6804 se debe almacenar en bloques de 6 bytes.
  El array 2D es como se muestra a continuación.

  |  tx_cfg[0][0]| tx_cfg[0][1] |  tx_cfg[0][2]|  tx_cfg[0][3]|  tx_cfg[0][4]|  tx_cfg[0][5]| tx_cfg[1][0] |  tx_cfg[1][1]|  tx_cfg[1][2]|  .....    |
  |--------------|--------------|--------------|--------------|--------------|--------------|--------------|--------------|--------------|-----------|
  |IC1 CFGR0     |IC1 CFGR1     |IC1 CFGR2     |IC1 CFGR3     |IC1 CFGR4     |IC1 CFGR5     |IC2 CFGR0     |IC2 CFGR1     | IC2 CFGR2    |  .....    |

*/

uint8_t rx_cfg[TOTAL_IC][8];
/*
  El rx_cfg[][8] almacena los datos que son leidos de los LTC6804-1 en Daisy-chain.
  Los datos de cada IC son almacenados en bloques de 8 bytes.
  A continuación se muestra la distribución del array 2D.

  |rx_config[0][0]|rx_config[0][1]|rx_config[0][2]|rx_config[0][3]|rx_config[0][4]|rx_config[0][5]|rx_config[0][6]  |rx_config[0][7] |rx_config[1][0]|rx_config[1][1]|  .....    |
  |---------------|---------------|---------------|---------------|---------------|---------------|-----------------|----------------|---------------|---------------|-----------|
  |IC1 CFGR0      |IC1 CFGR1      |IC1 CFGR2      |IC1 CFGR3      |IC1 CFGR4      |IC1 CFGR5      |IC1 PEC High     |IC1 PEC Low     |IC2 CFGR0      |IC2 CFGR1      |  .....    |

*/


uint16_t aux_codes[TOTAL_IC][6];
/*
  The GPIO codes will be stored in the aux_codes[][6] array in the following format:

  |  aux_codes[0][0]| aux_codes[0][1] |  aux_codes[0][2]|  aux_codes[0][3]|  aux_codes[0][4]|  aux_codes[0][5]| aux_codes[1][0] |aux_codes[1][1]|  .....    |
  |-----------------|-----------------|-----------------|-----------------|-----------------|-----------------|-----------------|---------------|-----------|
  |IC1 GPIO1        |IC1 GPIO2        |IC1 GPIO3        |IC1 GPIO4        |IC1 GPIO5        |IC1 Vref2        |IC2 GPIO1        |IC2 GPIO2      |  .....    |
*/


/***********************************************************************
  SETUP
 ***********************************************************************/
void setup(){
  for (uint8_t i=0; i<TOTAL_IC; i++){ //Se inicializa el array de los V de las celdas
    for(uint8_t j=0 ; j<12 ; j++){
      cell_codes[i][j] = 65525;
    }
  }
  Serial.begin(115200);
  #ifdef SERIAL_DEBUG
    //Serial.begin(115200);
    print_config(tx_cfg, TOTAL_IC);
  #endif


  LTC6804_initialize();  //Inicializa el LTC6804
  init_cfg(tx_cfg, TOTAL_IC);      //Inicializa el array de configuración del 6804 a los valores por defecto

  read_eeprom_ltc(TOTAL_IC, tx_cfg); //Actualiza el array de config del LTC6804 con los valores almacenados en la EEPROM
  read_eeprom_atmega(UV_THR, OV_THR, N_NTC,TOTAL_CELL,UVBAT_THR, OVBAT_THR, MAX_VCELL_DIFF, BALANCING_TYPE, NCELL_PARALLEL, CURRENT_OFFSET, TSLEEP); //Se leen las configuraciones del ATMEGA desde EEPROM

  init_mcp2515(CAN_125KBPS, MCP_8MHZ, 0); //Se iniciliaza el MCP2515 para comunicacion CAN a 125 KBPS
  mcp2515.setConfigMode(); //Se configuran las mascaras del MCP2515 para aceptar solo mensajes con ID 0b000000xxxxxx
  mcp2515.setFilterMask(MCP2515::MASK0, false, 0b11111000000);
  mcp2515.setFilterMask(MCP2515::MASK1, false, 0b11111000000);
  mcp2515.setNormalMode();

  attachInterrupt(0, can_msg_rcv, FALLING); //Se configura interrupcion al recibir mensaje CAN de configuracion

  //Configuración de los mensajes CAN
  config_can_msg (canBatMsg1, BAT_MSG1_ID, 8); //Se indica el mensaje CAN, el ID (entero decimal) y el DLC (entero decimal)
  config_can_msg (canBatMsg2, BAT_MSG2_ID, 8);
  config_can_msg (canBatMsg3, BAT_MSG3_ID, 8);
  config_can_msg (canTempMsg1, TEMP_MSG1_ID, 8);
  config_can_msg (canTempMsg2, TEMP_MSG2_ID, 8);
  config_can_msg (canTempMsg3, TEMP_MSG3_ID, 8);
  config_can_msg (canTempMsg4, TEMP_MSG4_ID, 8);
  config_can_msg (warning, WARNING_ID, 1);
  config_can_msg (canCurrentMsg, CURRENT_MSG_ID, 4);
  config_can_msg (canSOCMsg, SOC_MSG_ID, 2);
  LTC6804_initialize();
}

/**********************************************************************
  LOOP
***********************************************************************/

void loop() {
  static unsigned long time_last_msg_bat = 0;
  static unsigned long time_last_msg_current = 0;
  static unsigned long time_last_msg_temp = 0;
  static unsigned long time_last_msg_soc = 0;
  static float T_max = 0.0;
  //Comienza la lectura y conversión de las tensiones leidas por el LTC6804
  read_cell_voltage (TOTAL_IC, TOTAL_CELL, tx_cfg, cell_codes);

  //Se convierten los valores de la tensión de las celdas a mensaje CAN
  cell_voltage_to_can_msg (cell_codes, TOTAL_IC, TOTAL_CELL, canBatMsg1, canBatMsg2, canBatMsg3);

  if (millis() > time_last_msg_bat + (TSLEEP * 15)){
    //Se envia el valor de las tensiones de celdas por CAN
    send_can_msg(canBatMsg1);

    if(TOTAL_CELL > 4){ //Si hay mas de 4 celdas se envia segundo y tercer mensaje CAN
      send_can_msg(canBatMsg2);
    }
    if(TOTAL_CELL >= 9){
      send_can_msg (canBatMsg3);
    }
    time_last_msg_bat = millis();
  }

  //Se mide la corriente y se envía el valor por CAN
  int32_t current = get_current (SAMPLESNUMBER, SENSIBILITY_CURRENT, PIN_CURRENT_SENSOR, CURRENT_OFFSET);
  current_to_can_msg (current, canCurrentMsg);
  if (millis() > time_last_msg_current + (TSLEEP *15)){
    send_can_msg(canCurrentMsg);
    time_last_msg_current = millis();
  }

  //Verificar y activar el balanceo de las celdas necesarias
  if(force_bal_flag == false){ //Si no se ha forzado el balanceo, se comprueba el tipo de balanceo
    switch(BALANCING_TYPE){
      case 0:{ //Caso de balanceo desactivado
        force_balancing (TOTAL_IC, tx_cfg, 0b00000000, true); //No se balanceo ninguna celda
        force_balancing (TOTAL_IC, tx_cfg, 0b00000000, false); //Se balancea celdas 1 a 8
      break;}
      case 1:{ //Balanceo solo durante la carga. Corriente medida es positiva
        if (current >=0){ //Si se esta cargando se balancea
          balancing(TOTAL_IC,  cell_codes, tx_cfg, MAX_VCELL_DIFF, TOTAL_CELL, OV_THR, UV_THR );
        }
        else{ //Si no se esta descargando, no se balancea
          force_balancing (TOTAL_IC, tx_cfg, 0b00000000, true); //Se dejan de balancear las celdas 1 a 8
          force_balancing (TOTAL_IC, tx_cfg, 0b00000000, false); //Se dejan de balancear las celdas 9 a 12
        }
        break;
      }
      case 2:{ //Balanceo solo durante la descarga
        if(current <=0){ //Balanceo solo durante la descarga. Corriente medida es negativa
          balancing(TOTAL_IC,  cell_codes, tx_cfg, MAX_VCELL_DIFF, TOTAL_CELL, OV_THR, UV_THR );
        }
        else{ //Si no se esta descargando, no se balancea
          force_balancing (TOTAL_IC, tx_cfg, 0b00000000, true); //Se dejan de balancear las celdas 1 a 8
          force_balancing (TOTAL_IC, tx_cfg, 0b00000000, false); //Se dejan de balancear las celdas 9 a 12
        }
        break;
      }
      case 3:{//Balanceo tanto durante la descarga como la carga
        balancing(TOTAL_IC,  cell_codes, tx_cfg, MAX_VCELL_DIFF, TOTAL_CELL, OV_THR, UV_THR );
        break;
      }
    }
  }

  //Calcular tensión total y generar aviso de tension o Temperatura
  float voltaje_total = calc_volt_total(cell_codes, TOTAL_IC, TOTAL_CELL);

  bool genera_warning = warning_msg(voltaje_total, UVBAT_THR, OVBAT_THR, T_max, warning);
  if (genera_warning) {
    //Se envia el aviso
    send_can_msg(warning);
  }

  //Se miden todas las temperaturas de las celdas y se guardan en cell_temp. Además se obtiene la T_max
  T_max = measure_all_temp(cell_temp, N_NTC, BETTA, To, Ro, Raux, Vcc, PIN_ANALOG_NTC, PIN_SYNC_MUX);

  //Se conviertes las temperaturas a mensajes CAN
  temp_to_can_msg(cell_temp, N_NTC, canTempMsg1, canTempMsg2, canTempMsg3, canTempMsg4);

  if (millis() > time_last_msg_temp + (TSLEEP *15)){
  //Se envian las Temperaturas de las celdas por CAN. Cada mensaje tiene 8 temperaturas
    send_can_msg(canTempMsg1); //Primeras 8 NTC
    if (N_NTC >8){ //NTC de 9 a 16
      send_can_msg(canTempMsg2);
    }
    if (N_NTC > 16){ //NTC de 17 a 24
      send_can_msg(canTempMsg3);
    }
    if (N_NTC >24){ //NTC de 24 a 32
      send_can_msg(canTempMsg4);
    }
    time_last_msg_temp = millis();
  }

  //Estimar SOH y SOC y enviarlos por CAN
  float SOC =  calculate_SOC(float(current/NCELL_PARALLEL), float(voltaje_total/TOTAL_CELL), internal_resistor);//Devuelve el SOC en porcentaje 0-100%
  SOC_can_msg(SOC, canSOCMsg);// Se codifica el SOC en un mensaje CAN de 2 bytes. Se envia el porcentaje multiplicado por 1000
  if (millis() > time_last_msg_soc + (TSLEEP *15)){
    send_can_msg(canSOCMsg);
    time_last_msg_soc = millis();
  }

  /*for (uint8_t i=0 ; i < TSLEEP; i++){
    LowPower.powerDown(SLEEP_15MS, ADC_OFF, BOD_ON);
  }*/

} //FIN DEL LOOP


/************************************
  Se configura el mensaje CAN
 **************************************/
void config_can_msg (struct can_frame &can_msg, const uint8_t can_id, const uint8_t can_dlc) {
  can_msg.can_id = can_id;
  can_msg.can_dlc = can_dlc;
}


/************************************
 * Función que codifica la corriente en un mensaje CAN. Se dividen los 32 bits del float en 4 bytes del mensaje CAN
 ****************************************/
void current_to_can_msg ( int32_t current, struct can_frame &canCurrentMsg){
  canCurrentMsg.data[0] = (current) ; //Los 8 bits menos significados son el primer byte
  canCurrentMsg.data[1] = (current >> 8) ; //Los siguientes 8 bits del numero de 32 bits son el byte1
  canCurrentMsg.data[2] = (current >> 16);
  canCurrentMsg.data[3] = (current >> 24);
}


/************************************
  Se codifican las tensiones en mensajes CAN. Función
  Sigue este formato

  |  can_frame[7]      |    can_frame[6]     |    .....     |     can_frame[1]   |      can_frame[0]   |
  |--------------------|---------------------|--------------|--------------------|---------------------|
  | cell3 MSB          |     cell3 LSB       |    .....     |    cell0 MSB       |     cell0 LSB       |
  | cell_code[0][3] MSB|  cell_code[0][3] LSB|    .....     | cell_code[0][0] MSB|  cell_code[0][0] LSB|

 **************************************/
void cell_voltage_to_can_msg ( uint16_t cell_codes[][12], const uint8_t TOTAL_IC, const uint8_t TOTAL_CELL, struct can_frame &canBatMsg1) {
  for (uint8_t i = 0; i < TOTAL_IC; i++) {
    for (uint8_t j = 0 ; j < TOTAL_CELL; j++) { //Cada medición ocupa 2 bytes (cell_codes son arrays de 16 bits)
      //Este algoritmo permite rellenar un mensaje de 8 bytes que contenga los 4 valores de 16 bits de las celdas. Con MSB los valores de la celda más alta
      //y LSB los valores LSB de la celda más baja
      canBatMsg1.data[2 * j] = cell_codes[i][j]; //Se toma la parte baja del registro de 16 bits
      canBatMsg1.data[2 * j + 1] = cell_codes[i][j] >> 8; //Se toma la parte alta del registro de 16 bits y se guarda en el byte siguiente del mnsje
    }
  }
}

void cell_voltage_to_can_msg (const uint16_t cell_codes[][12], const uint8_t TOTAL_IC, const uint8_t TOTAL_CELL, struct can_frame &canBatMsg1,
                              struct can_frame &canBatMsg2) {
  for (uint8_t i = 0; i < TOTAL_IC; i++) {
    //Las primeras 4 celdas en el Mensaje 1 (canBatMsg1)
    for (uint8_t j = 0 ; j < 4; j++) { //Cada medición ocupa 2 bytes (cell_codes son arrays de 16 bits)
      //Este algoritmo permite rellenar un mensaje de 8 bytes que contenga los 4 valores de 16 bits de las celdas. Con MSB los valores de la celda más alta
      //y LSB los valores LSB de la celda más baja
      canBatMsg1.data[2 * j] = cell_codes[i][j]; //Se toma la parte baja del registro de 16 bits
      canBatMsg1.data[2 * j + 1] = cell_codes[i][j] >> 8; //Se toma la parte alta del registro de 16 bits y se guarda en el byte siguiente del mnsje
    }
  }
  for (uint8_t i = 0; i < TOTAL_IC; i++) {
    //Las celdas 4-7 en el Mensaje 2 (canBatMsg2)
    for (uint8_t j = 4 ; j < 8; j++) { //Cada medición ocupa 2 bytes (cell_codes son arrays de 16 bits)
      //Este algoritmo permite rellenar un mensaje de 8 bytes que contenga los 4 valores de 16 bits de las celdas. Con MSB los valores de la celda más alta
      //y LSB los valores LSB de la celda más baja
      canBatMsg2.data[2*(j - 4)] = cell_codes[i][j]; //Se toma la parte baja del registro de 16 bits
      canBatMsg2.data[2*(j - 4) + 1] = cell_codes[i][j] >> 8; //Se toma la parte alta del registro de 16 bits y se guarda en el byte siguiente del mnsje
    }
  }
}

void cell_voltage_to_can_msg (const uint16_t cell_codes[][12], const uint8_t TOTAL_IC, const uint8_t TOTAL_CELL, struct can_frame &canBatMsg1,
                              struct can_frame &canBatMsg2, struct can_frame &canBatMsg3 ) {
  for (uint8_t i = 0; i < TOTAL_IC; i++) {
    //Las primeras 4 celdas en el Mensaje 1 (canBatMsg1)
    for (uint8_t j = 0 ; j < 4; j++) { //Cada medición ocupa 2 bytes (cell_codes son arrays de 16 bits)
      //Este algoritmo permite rellenar un mensaje de 8 bytes que contenga los 4 valores de 16 bits de las celdas. Con MSB los valores de la celda más alta
      //y LSB los valores LSB de la celda más baja
      canBatMsg1.data[2 * j] = cell_codes[i][j]; //Se toma la parte baja del registro de 16 bits
      canBatMsg1.data[(2 * j) + 1] = cell_codes[i][j] >> 8; //Se toma la parte alta del registro de 16 bits y se guarda en el byte siguiente del mnsje
    }
  }
  for (uint8_t i = 0; i < TOTAL_IC; i++) {
    //Las celdas 4-7 en el Mensaje 2 (canBatMsg2)
    for (uint8_t j = 4 ; j < 8; j++) { //Cada medición ocupa 2 bytes (cell_codes son arrays de 16 bits)
      //Este algoritmo permite rellenar un mensaje de 8 bytes que contenga los 4 valores de 16 bits de las celdas. Con MSB los valores de la celda más alta
      //y LSB los valores LSB de la celda más baja
      canBatMsg2.data[2*(j - 4)] = cell_codes[i][j]; //Se toma la parte baja del registro de 16 bits
      canBatMsg2.data[2*(j - 4) + 1] = cell_codes[i][j] >> 8; //Se toma la parte alta del registro de 16 bits y se guarda en el byte siguiente del mnsje
    }
  }
  for (uint8_t i = 0; i < TOTAL_IC; i++) {
    //Las celdas 4-7 en el Mensaje 2 (canBatMsg2)
    for (uint8_t j = 8 ; j < 12; j++) { //Cada medición ocupa 2 bytes (cell_codes son arrays de 16 bits)
      //Este algoritmo permite rellenar un mensaje de 8 bytes que contenga los 4 valores de 16 bits de las celdas. Con MSB los valores de la celda más alta
      //y LSB los valores LSB de la celda más baja
      canBatMsg3.data[2 * (j - 8)] = cell_codes[i][j]; //Se toma la parte baja del registro de 16 bits
      canBatMsg3.data[2 * (j - 8) + 1] = cell_codes[i][j] >> 8; //Se toma la parte alta del registro de 16 bits y se guarda en el byte siguiente del mnsje
    }
  }
}


/************************************
  Se verifica si generar un aviso de tensión baja de batería
 **************************************/
bool warning_msg(const float voltaje_total, const float umbral_vacio, const float umbral_cargado, const float T_max, struct can_frame warning) {
  static uint8_t estado_V = 1; //Se parte en el caso 1, de batería no llena pero no descargada
  static uint8_t estado_ant_V = 1;
  static uint8_t estado_T = 4; //Se parte en el caso 1, de batería no llena pero no descargada
  static uint8_t estado_ant_T = 4;

  //Caso de voltaje muy bajo
  if (voltaje_total < (umbral_vacio - 0.1)) { //Se restan 0.1 V para dejar una histéresis
    warning.data[0] = warning.data[0] | 0b00000001; //Bit 0 a 1 almacena info de bajo voltaje. A 0 no hay bajo V
    warning.data[0] = warning.data[0] & 0b11111101; //pone bit 1 a 0 para indicar batería no cargada. Valor dle bit 1 a 1 indica batería cargada
    estado_ant_V = estado_V;
    estado_V = 0;
  #ifdef SERIAL_DEBUG
      Serial.println("Vpack muy bajo");
  #endif
  }
  //Caso voltaje entre mínimo y máximo
  else if ((voltaje_total > (umbral_vacio + 0.1)) && voltaje_total < umbral_cargado) {
    warning.data[0] = warning.data[0] & 0b11111110; //Bit 0 a 0 para indicar que no hay voltaje demasiado bajo
    warning.data[0] = warning.data[0] & 0b11111101 ; //Bit 1 a 0 indica batería NO está cargada totalmente
    estado_ant_V = estado_V;
    estado_V = 1;
  #ifdef SERIAL_DEBUG
      Serial.println("Vpack OK");
  #endif
  }
  //Caso de batería llena
  else if (voltaje_total >= umbral_cargado) {
    warning.data[0] = warning.data[0] & 0b11111110; //Poner bit 1 a 0 para indicar batería NO tiene bajo voltaje
    warning.data[1] = warning.data[0] | 0b00000010; //Batería sobre-cargada. Poner bit 1 a valor 1 para indicar batería por encima del V máximo
    estado_ant_V = estado_V;
    estado_V = 2;
  #ifdef SERIAL_DEBUG
      Serial.println("Vpack superior al máximo");
  #endif
  }


  if (T_max > 60) { //si supera 60 se avisa de sobretemperatura
    warning.data[0] = warning.data[0] | 0b00000100;  //Bit 2 a 1 indica Temperatura máxima excedida
    estado_ant_T = estado_T;
    estado_T = 3;
  #ifdef SERIAL_DEBUG
      Serial.println("Temp. máx. excedida");
  #endif
  }
  else if (T_max < 50) { //Hasta no bajar a 50ºC no se quita aviso de sobretemperatura
    warning.data[0] = warning.data[0] & 0b11111011; //se pone a 0 el bit 2 al bajar la Tª nuevamente por debajo de 50ºC
    estado_ant_T = estado_T;
    estado_T = 4;
  #ifdef SERIAL_DEBUG
      Serial.println("Temp. adecuada");
  #endif
  }


  if ((estado_ant_V != estado_V) || (estado_ant_T != estado_T)) { //Si hay algún cambio de estado
  #ifdef SERIAL_DEBUG
      Serial.println("Cambios en las advertencias. Activando Warning");
      Serial.println("Estado anterior(V) | Estado actual(V)");
      Serial.print(estado_ant_V);
      Serial.print("     |   ");
      Serial.println(estado_V);
      Serial.println("Estado anterior(T) | Estado actual(T)");
      Serial.print(estado_ant_T);
      Serial.print("        |   ");
      Serial.println(estado_T);
  #endif
    return true; //Devuelve true si hay un cambio de estado para así enviar un nuevo mensaje warning
  }
  #ifdef SERIAL_DEBUG
    Serial.println("No hay cambio en advertencias. No warning");
  #endif
  return false; //Devuelve false si no hay cambio para así no enviar un nuevo warning
}
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

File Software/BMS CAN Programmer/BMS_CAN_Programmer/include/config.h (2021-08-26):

#ifndef config_h
#define config_h

/************************************
  Constantes y parámetros
  ***********************************/
#define CFGR0_addr 1
#define VUV_addr 2
#define VOV_addr 3
#define DCTO_addr 4
#define NCELL_addr 5
#define N_NTC_addr 6
#define TSLEEP_addr 7
#define MAX_DIFF_CELL_addr 8
#define BALANCING_TYPE_addr 9
#define NCELL_PARALLEL_addr 10
#define CURRENT_OFFSET_addr 11


//ID de los mensajes CAN en decimal
#define BAT_MSG1_ID 0x40
#define BAT_MSG2_ID 0x41
#define BAT_MSG3_ID 0x42
#define TEMP_MSG1_ID 0x43
#define TEMP_MSG2_ID 0x44
#define TEMP_MSG3_ID 0x45
#define TEMP_MSG4_ID 0x46
#define SOC_MSG_ID 0x47
#define SOH_MSG_ID 0x48
#define CURRENT_MSG_ID 0x49


#define WARNING_ID 0
#define VUV_MSG_ID 0X02
#define VOV_MSG_ID 0x03
#define DCTO_MSG_ID 0x04
#define NCELL_MSG_ID 0x05
#define N_NTC_MSG_ID 0x06
#define TSLEEP_MSG_ID 0x07
#define BAL1TO8_MSG_ID 0x08
#define BAL9TO12_MSG_ID 0x09
#define ASK_CONFIG_MSG_ID 0x0B
#define ANSWER_CONFIG_MSG_ID 0x0C
#define ANSWER_CONFIG_MSG_2_ID 0x11
#define MAX_DIFF_CELL_MSG_ID 0x0D
#define TYPE_BALANCING_MSG_ID 0x0E
#define NCELL_PARALLEL_MSG_ID 0x0F
#define CURRENT_OFFSET_MSG_ID 0x10

//ID de los mensajes Seriales
#define VUV_SERIAL_ID 'A'
#define VOV_SERIAL_ID 'B'
#define DCTO_SERIAL_ID 'C'
#define NCELLS_SERIAL_ID 'D'
#define NTEMPS_SERIAL_ID 'E'
#define TSLEEP_SERIAL_ID 'F'
#define BAL1_8_SERIAL_ID 'G'
#define BAL9_12_SERIAL_ID 'H'
#define MAX_DIFF_CELL_SERIAL_ID 'I'
#define TYPE_BALANCING_SERIAL_ID 'J'
#define NCELLS_PARALLEL_SERIAL_ID 'K'
#define CURRENT_OFFSET_SERIAL_ID 'L'
#define BAT_MSG1_SERIAL_ID 'M'
#define BAT_MSG2_SERIAL_ID 'N'
#define BAT_MSG3_SERIAL_ID 'O'
#define TEMP_MSG_SERIAL_ID 'P'
#define CURRENT_MSG_SERIAL_ID 'Q'
#define SOC_MSG_SERIAL_ID 'T'
#define SOH_MSG_SERIAL_ID 'U'
#define ASK_CONFIG_SERIAL_ID 'Z'


#define PIN_SYNC_MUX 8 //Pin del CS del ADG731  (D8 que es el PB0 en ATMega 328P)
#define PIN_CURRENT_SENSOR A1 //Pin al que se conecta el sensor de corriente
#define PIN_ANALOG_NTC A0 //Pin para la lectura de las Temperaturas
#define SENSIBILITY_CURRENT 0.066 //Sensibilidad del sensor de corriente ACS712 30A
#define SAMPLESNUMBER 100 //Numero de muestras tomadas para hacer la media de la corriente

//#define SERIAL_DEBUG

#endif

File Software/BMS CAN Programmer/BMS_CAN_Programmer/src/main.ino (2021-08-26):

#include <Arduino.h>
#include "config.h"
#include "serial_lib.h"
#include "mcp2515.h"

String inReadString = "";

MCP2515 mcp2515(9);

struct can_frame can_msg_in;
struct can_frame can_msg_out;


void can_msg_rcv(){
  noInterrupts();
  if(mcp2515.readMessage(&can_msg_in) == MCP2515::ERROR_OK){
    //Serial.print("Mensaje recibido Correctamente. ID:");
    //Serial.println(can_msg_in.can_id, DEC);
    switch (can_msg_in.can_id){
    case ANSWER_CONFIG_MSG_ID:{ //Recibir configuraciones del BMS
      uint8_t aux = can_msg_in.data[0];
      Serial.print(VUV_SERIAL_ID);
      Serial.println(aux, DEC); //Envia por serie el valor de VUV almacenado
      aux = can_msg_in.data[1];
      Serial.print(VOV_SERIAL_ID);
      Serial.println (aux, DEC); //Envia por serie el valor de VOV almacenado
      aux = can_msg_in.data[2];
      Serial.print(DCTO_SERIAL_ID);
      Serial.println(aux, DEC); //Envia por serie el valor de DCTO almacenado
      aux = can_msg_in.data[3];
      Serial.print(NCELLS_SERIAL_ID);
      Serial.println(aux, DEC); //Envia por serie el numero de celdas almacenado (NCELL)
      aux = can_msg_in.data[4];
      Serial.print(NTEMPS_SERIAL_ID);
      Serial.println (aux, DEC); //Envia por serie el numero de NTC (N_NTC)
      aux = can_msg_in.data[5];
      Serial.print(MAX_DIFF_CELL_SERIAL_ID);
      Serial.println(aux, DEC); //Envia por serie el Valor de máximo V de diferencia (en mV) entre celdas
      aux = can_msg_in.data[6];
      Serial.print(BAL1_8_SERIAL_ID);
      Serial.println(aux, DEC); //Devuelve las celdas que están balanceandose en ese instante de la 1 a la 8
      aux = can_msg_in.data[7];
      Serial.print(BAL9_12_SERIAL_ID);
      Serial.println(aux, DEC); //Devuelve las celdas entre la 9 y la 12 que se estan balanceando (4 primeros bits)
      break;}
    case ANSWER_CONFIG_MSG_2_ID:{ //Recibir 2 mensaje de configuraciones del BMS
      uint8_t aux = can_msg_in.data[0];
      Serial.print(NCELLS_PARALLEL_SERIAL_ID);
      Serial.println(aux, DEC); //Envia por serie el valor de numero de celdas en paralelo
      int16_t current_offset = int16_t(int16_t(uint16_t((can_msg_in.data[1] << 8)) | uint16_t(can_msg_in.data[2]) )- 32767); //Se reconstruye el offset de corriente desde 2 bytes
      Serial.print(CURRENT_OFFSET_SERIAL_ID);
      Serial.println(current_offset, DEC); //Envia por serie el offset
      aux = can_msg_in.data[3];
      Serial.print(TSLEEP_SERIAL_ID);
      Serial.println(aux, DEC); //Envia por serie el valor del factor que multiplica a 15 ms al tsleep
      aux = can_msg_in.data[4];
      Serial.print(TYPE_BALANCING_SERIAL_ID);
      Serial.println(aux, DEC); //Envia por serie el tipo de balanceo
      break;}

    case BAT_MSG1_ID: //Se recibe el mensaje CAN de las celdas 1 a 4
      for (int i=0; i<4 ; i++){
        Serial.print(BAT_MSG1_SERIAL_ID);
        Serial.print(i+1);
        uint16_t aux = (can_msg_in.data[(2*i)+1] << 8) | can_msg_in.data[2*i];
        Serial.println(aux, DEC);
      }
      break;
    case BAT_MSG2_ID://Se recibe el mensaje CAN de las celdas 5 a 8
      for (int i=0; i<4 ; i++){
        Serial.print(BAT_MSG2_SERIAL_ID);
        Serial.print(i+1);
        uint16_t aux = (can_msg_in.data[2*i+1] << 8) | can_msg_in.data[2*i];
        Serial.println(aux, DEC);
      }
      break;
    case BAT_MSG3_ID:
      for (int i=0; i<4 ; i++){
        Serial.print(BAT_MSG3_SERIAL_ID);
        Serial.print(i+1);
        uint16_t aux = (can_msg_in.data[2*i+1] << 8) | can_msg_in.data[2*i];
        Serial.println(aux, DEC);
      }
      break;
    case TEMP_MSG1_ID: //Se recibe por CAN las 8 primeras temperaturas
      for (int i=1; i<9; i++){
        Serial.print(TEMP_MSG_SERIAL_ID);
        Serial.print("0");
        Serial.print(i, DEC);
        uint8_t aux = can_msg_in.data[i-1];
        Serial.println(aux, DEC); //Se envia M01 y el valor para la NTC0, M02 para NTC num 2...
      }
      break;
    case TEMP_MSG2_ID: //Temperaturas de las NTC 9 a 16
      Serial.print(TEMP_MSG_SERIAL_ID);
      Serial.print("09");
      Serial.println(can_msg_in.data[0], DEC); //Se envia P09 para la NTC numero 9
      for (int i=10; i<17; i++){
        Serial.print("P");
        Serial.print(i, DEC);
        uint8_t aux = can_msg_in.data[i-9];
        Serial.println(aux, DEC); //Se envia M10 y el valor para la NTC10, M11 para NTC num 11...
      }
      break;
    case TEMP_MSG3_ID: //Temperaturas de la NTC 17 a 25
      for (int i=17; i<25; i++){
        Serial.print(TEMP_MSG_SERIAL_ID);
        Serial.print(i, DEC);
        uint8_t aux = can_msg_in.data[i-17]; //Se envia M17 y el valor para la NTC17, M18 para NTC num 18...
        Serial.println(aux, DEC);
      }
      break;
    case TEMP_MSG4_ID:
    //Serial.println("Recibido 25 a 32");
      for (int i=25; i<33; i++){
        Serial.print(TEMP_MSG_SERIAL_ID);
        Serial.print(i, DEC);
        uint8_t aux = can_msg_in.data[i-25]; //Se envia M25 y el valor para la NTC25, M32 para NTC num 32...
        Serial.println(aux, DEC);
      }
      break;
    case CURRENT_MSG_ID:{ //Corriente medida de la batería
      int32_t current = 0;
      current = ((uint32_t(can_msg_in.data[3]) << 24)) | ((uint32_t(can_msg_in.data[2]) << 16)) | ((uint32_t(can_msg_in.data[1]) << 8)) | (uint32_t(can_msg_in.data[0])) ;
      Serial.print(CURRENT_MSG_SERIAL_ID);
      Serial.println(current, DEC); //Se envia la corriente en mA
    }
    case SOC_MSG_ID:{ // SOC del pack
      Serial.print(SOC_MSG_SERIAL_ID);
      uint16_t SOC = (uint16_t(can_msg_in.data[1]) << 8) | can_msg_in.data[0];
      Serial.println(SOC, DEC);
      break;}
    case SOH_MSG_ID:{ //SOH del pack
      Serial.print(SOH_MSG_SERIAL_ID);
      uint8_t aux = can_msg_in.data[0];
      Serial.println(aux, DEC);
      //Serial.println("U"+can_msg_in.data[0]); //Se envia el SOH que es un numero de 1 byte
      break;}
  } //Fin del Switch
  }
  interrupts();
}
void setup() {
  attachInterrupt(0, can_msg_rcv, FALLING); //Se configura interrupcion al recibir mensaje CAN
  Serial.begin(115200);
  mcp2515.reset();
  mcp2515.setBitrate(CAN_125KBPS, MCP_8MHZ);
  mcp2515.setNormalMode();
}
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

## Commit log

2021-08-26 Añadidos todos los codigos y las graficas generadas.
    [DL_RecordData0.csv, DL_Recordata_800mA.csv, DL_Recordata_800mA_ensayo1.csv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]
2021-09-20 añadidos graficos para el readme
2021-09-20 Reestructurado el repo.
    [CAN2Serial.csv, CAN2Serial.kicad_pcb, CAN2Serial.sch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]
2021-09-21 Añado la memoria del TFM
